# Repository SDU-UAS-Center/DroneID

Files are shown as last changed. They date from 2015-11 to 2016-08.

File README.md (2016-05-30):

# DroneID
This repository contains documentation of the DroneID project. DroneID is a research project launched by the University of Southern Denmark in collaboration with the Danish Transport and Construction Agency in 2015.

COPYRIGHT

The content of repository is copyrighted by the respective authors mentioned in documents etc. 

LICENSE

Documentation of DroneID prototype hardware is, unless other information is indicated within the documentation, released under an Attribution 4.0 International(CC BY 4.0) license http://creativecommons.org/licenses/by/4.0/

CONTACT INFORMATION

University of Southern Denmark
Kjeld Jensen
Cand.Scient., PhD
SDU UAS Center
Campusvej 55
DK-5230 Odense M
Denmark

kjen@mmmi.sdu.dk
Phone: +45 27781926

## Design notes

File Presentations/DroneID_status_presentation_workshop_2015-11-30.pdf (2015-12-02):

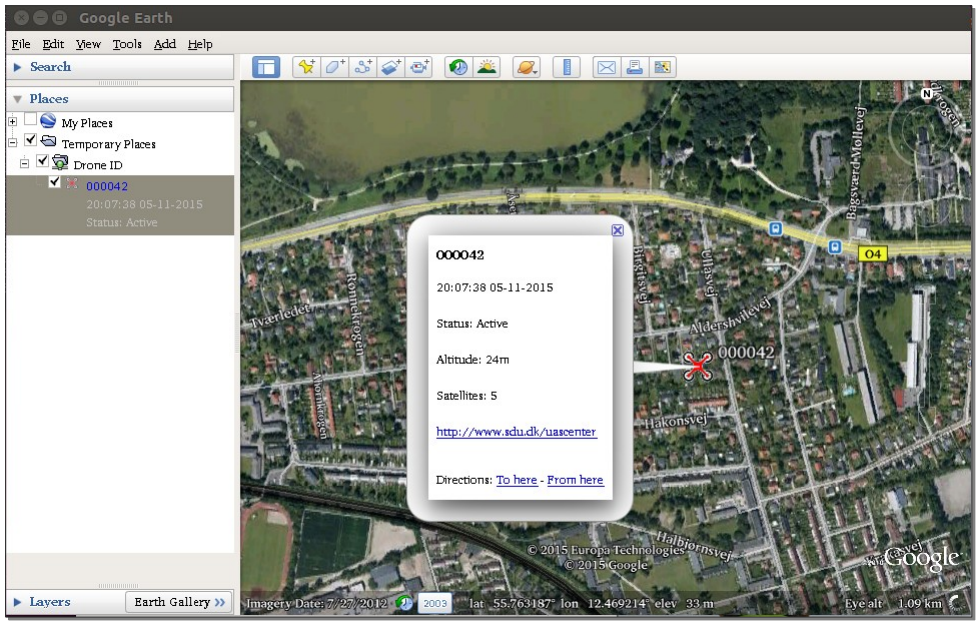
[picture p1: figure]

Workshop, Danish Transport and Construction Agency
Kjeld Jensen | November 30th, 2015
Cand.Scient. PhD
SDU UAS Center

## Drone ID

Drone identification and activity monitoring.

# Agenda

1.Welcome
2.Presentation of the project and tentative results.
3.Presentation of Apps for drone flight registration.
4.Presentation af a DroneID prototype based on on-site monitoring. 5.Feedback on the presentations.
6.Transport to the model airfield Celinevej, Amager.
7.Live demonstration of DroneID prototypes and access to drone flight information for authorities.
8.Feedback on demonstrations and conclusion at the model airfield.

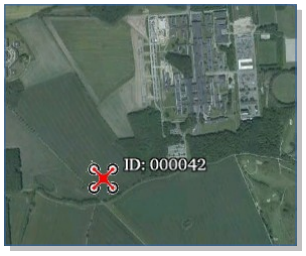
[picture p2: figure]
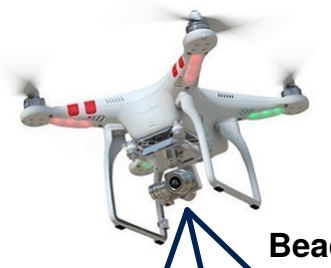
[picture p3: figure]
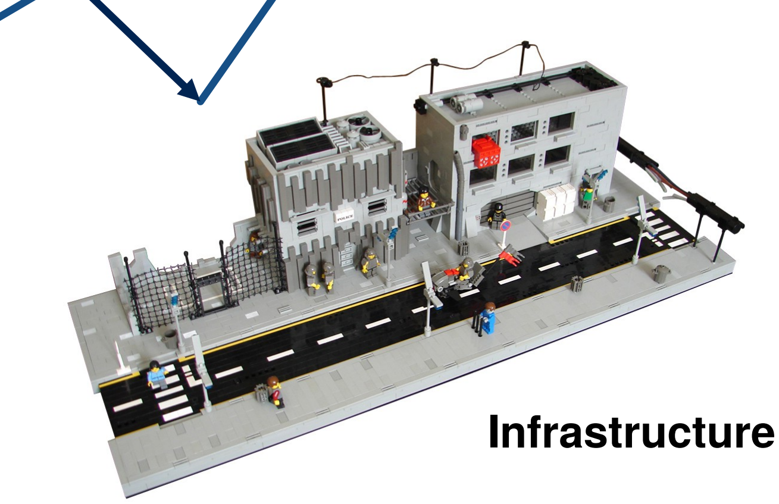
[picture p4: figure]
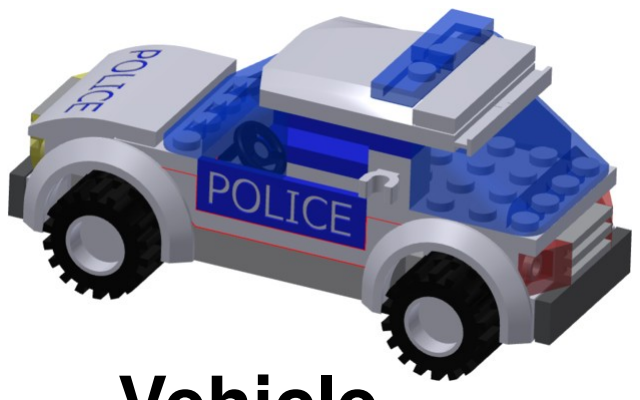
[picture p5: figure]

Handheld | Vehicle | Infrastructure

Access

# Drone ID architecture

On-site monitoring

Drone flight
pre-registration
Beacon | UAS Traffic Management (UTM)

Access

# Drone ID architecture

Network

Drone flight
pre-registration

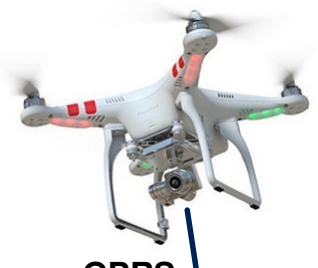
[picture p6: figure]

GPRS
modem

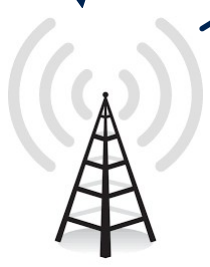
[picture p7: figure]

Cell tower

UAS Traffic
Management (UTM)

Flight
- Activity ID
- Status
- Start
- End
- Geofence
- Type
- Purpose

unique
planned/ongoing/completed/cancelled date and time
date and time
polygon describing boundary of operation commercial/recreational
specified e.g. training/inspection/transport etc. Drone
- Drone ID
- Type
- Payload
Pilot
- Name
- Address
- Phone
- Email
- Company
Authorization
- Status
- Authorities

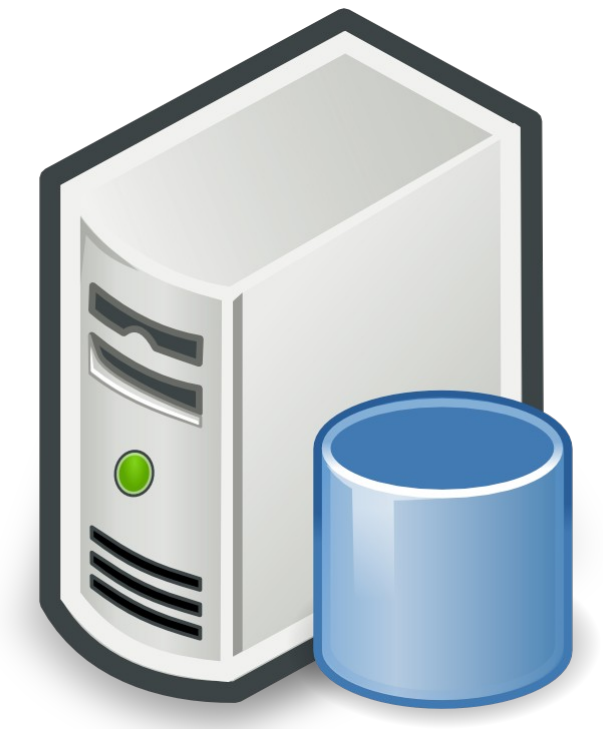
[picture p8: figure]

issued by authority
autofill if ID is available e.g. camera/sensor

not required/pending/approved/denied autofill based on location and drone ID

Activity records will automatically be validated (based on drone ID and geofencing) against static and dynamic restricted zones and submitted for approval by relevant authority.

# Drone ID record

UAS Traffic
Management (UTM)

Hardware
- Self contained, no interface to drone
- Very small form factor
- Light weight
- Low power operation
- Beacon interval 1 second
- Optional GPS and altimeter

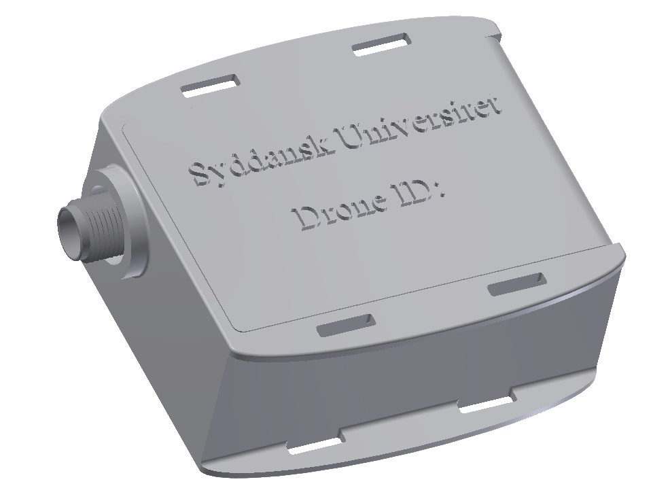
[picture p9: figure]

Beacon data
- Unique ID issued by authority
- Optional data (based on sensors):
- Position, elevation
- Velocity, heading
- Flight time
- Rolling key encryption to prevent unauthorized access and spoofing

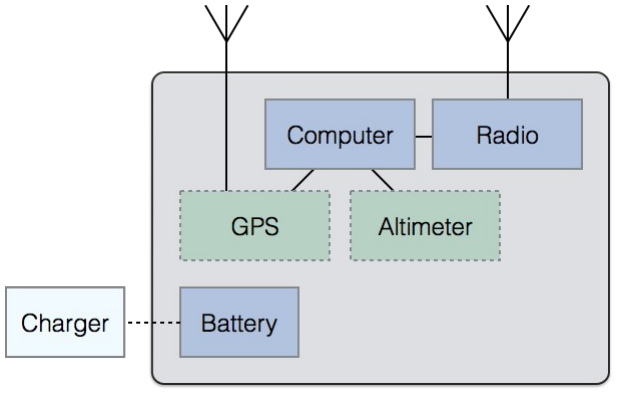
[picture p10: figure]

Hardware modules

# Drone ID prototype

# Drone ID beacon

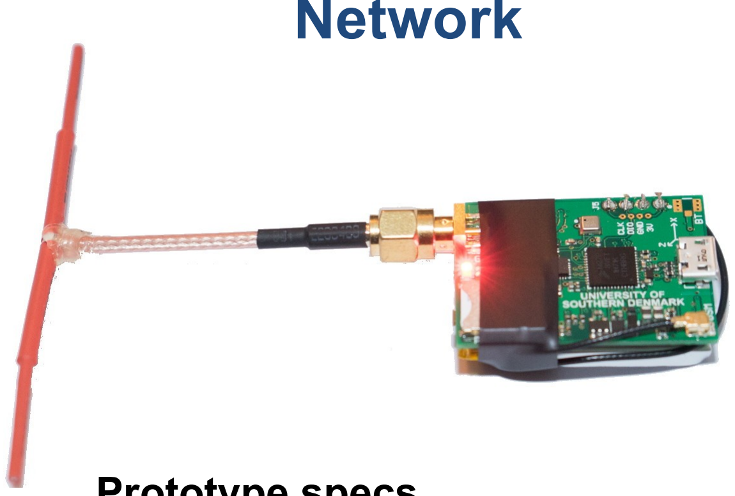
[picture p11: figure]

Prototype specs.
› GPRS modem
› GPS with external dipole antenna* › Weight approx. 20 g
› No connections to the drone
› Micro USB charging
› Battery lasts approx. 3 hours of flight time.

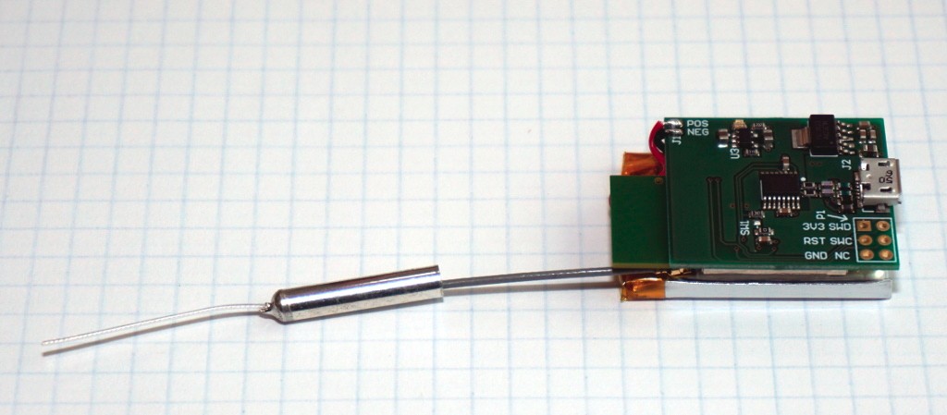
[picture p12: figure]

Prototype specs.
› Wifi radio
› External 2.4 GHz antenna › Weight approx. 10 g
› No connections to the drone › Micro USB charging
On site monitoring | Network
- Expected working range 500 - 1000m
- May require receiver hardware, antenna etc.
- No ground based infrastructure.
+ Lower size, weight, power.
+ Lower price
- Coverage limited by network (potential MVNO roaming). + No receiver hardware needed.
+ Infrastructure already established
- Higher size, weight, power.
- Higher price.
- Requires SIM card and subscription.

*The external dipole antenna allows installation of the DroneID on the side or beneath the drone body.

# Implementation road map

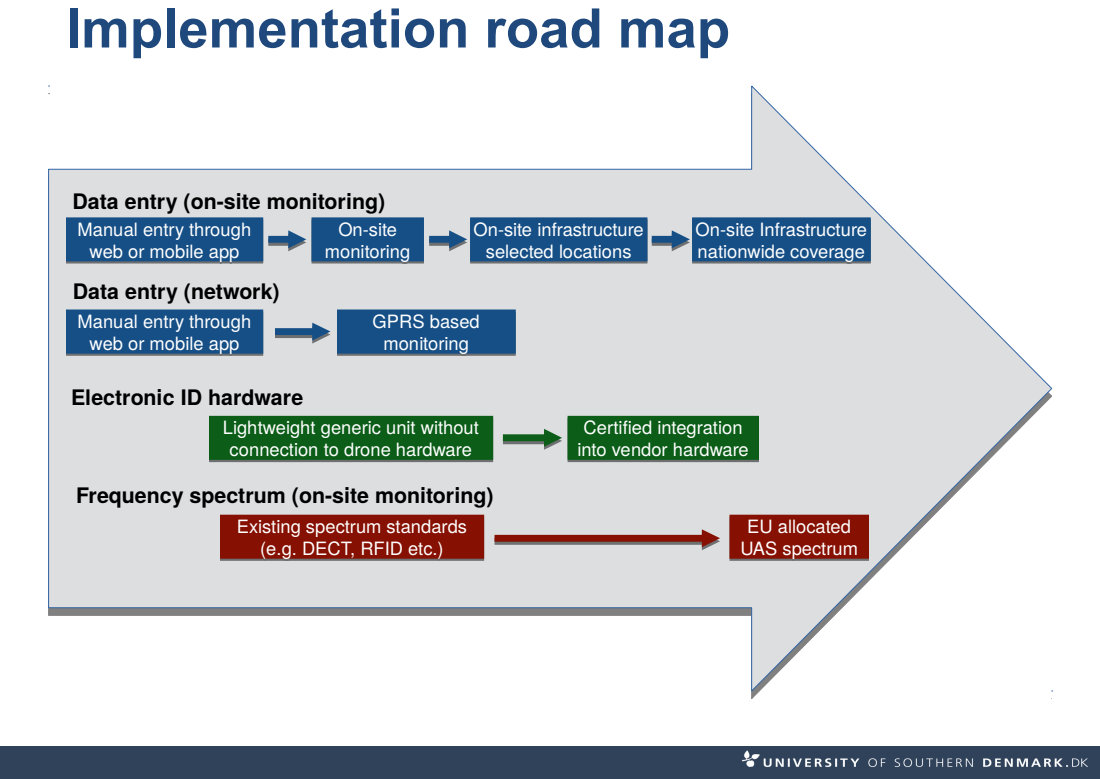
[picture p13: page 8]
On-site monitoring; EU allocated UAS spectrum; GPRS based monitoring

Data entry (on-site monitoring)
Manual entry through
web or mobile app
Data entry (network)
Electronic ID hardware

On-site infrastructure
selected locations

On-site Infrastructure
nationwide coverage

Lightweight generic unit without
connection to drone hardware

Certified integration
into vendor hardware

Frequency spectrum (on-site monitoring)

Existing spectrum standards
(e.g. DECT, RFID etc.)

# Current experiment

- 10 drone operators use a GPRS/GPS based DroneID prototype for one month starting mid November 2015.
- Workshops with drone operators, industrial partners, the police and other stakeholders focusing on user experience and feedback, on-site monitoring demonstrations, etc.
- Documentation completed ultimo 2015.
- Hardware and software developed by SDU within the project released as open source.

Companies contributing to the project
› DroneSoft ApS (mobile App showcase)
› Resiewe A/S (on-site DroneID prototype showcase)
› Scandinavian Avionics A/S (on-site DroneID prototype showcase)

Partners
› Danish Transport and Construction Agency › University of Southern Denmark
› UAS Denmark

# Startup workshops

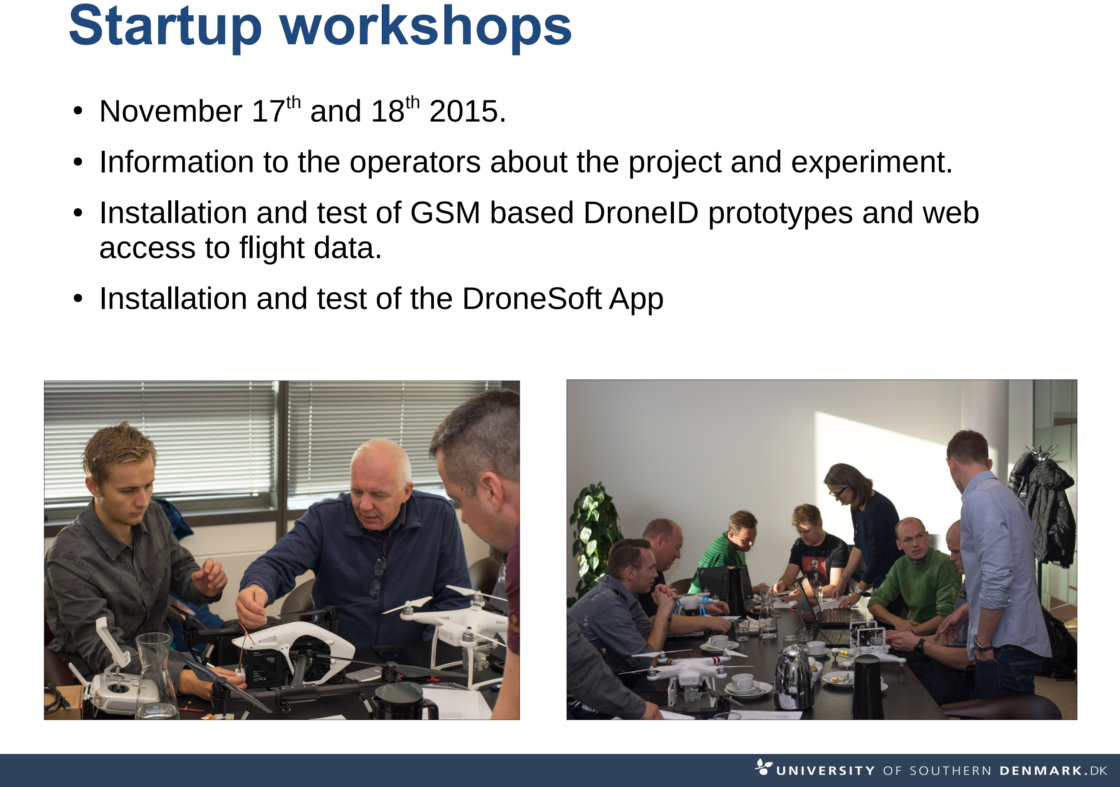
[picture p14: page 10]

- November 17th and 18th 2015.
- Information to the operators about the project and experiment.
- Installation and test of GSM based DroneID prototypes and web access to flight data.
- Installation and test of the DroneSoft App

# Installation guidelines

- DroneID must be installed on the side or beneath the drone body unless it can be ensured that the drone GPS antenna is not obstructed.
- DroneID must be installed as far away from other antennas with the DroneID logo (and hence GSM antenna) facing away from the drone body.
- DroneID GPS dipole antenna must have a clear view of the sky without obstructing the drone GPS antenna or touching the propellers. Antenna and cable should not be directly parallel to or near other antennas.
- Mount using electrical tape, velcro, cable binders etc.

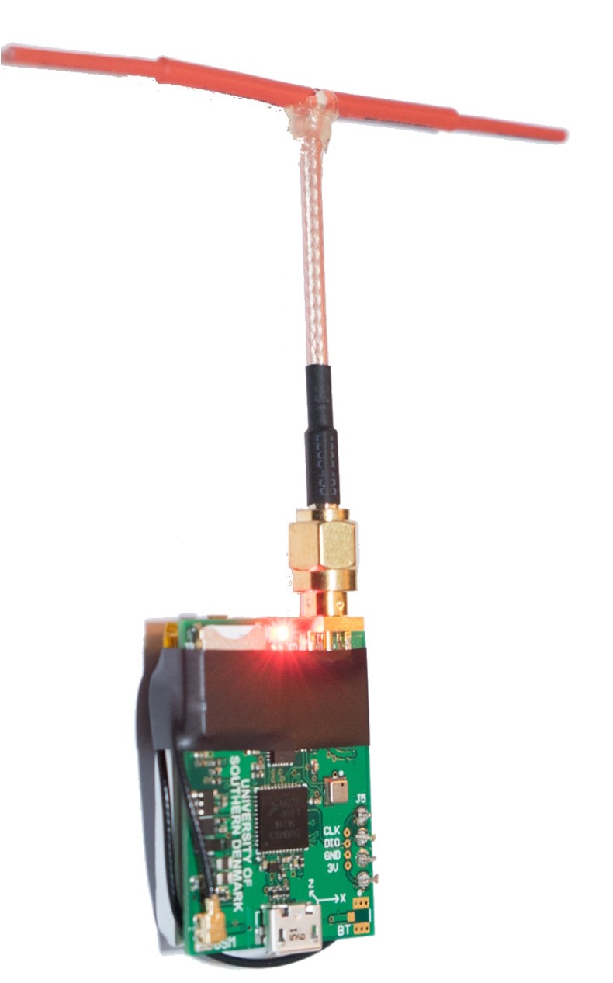
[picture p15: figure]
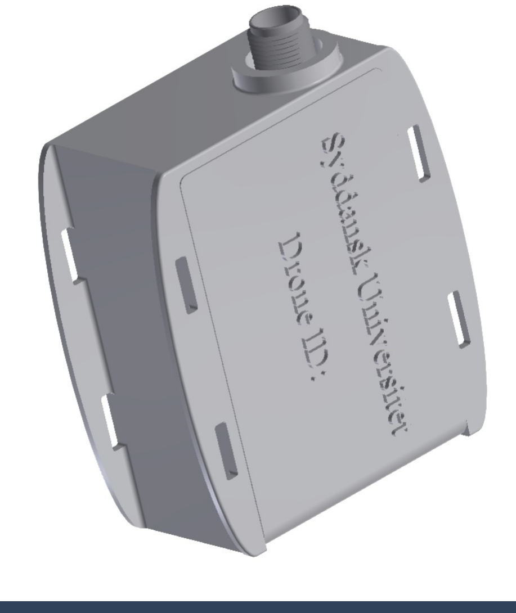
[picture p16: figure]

# Installation examples

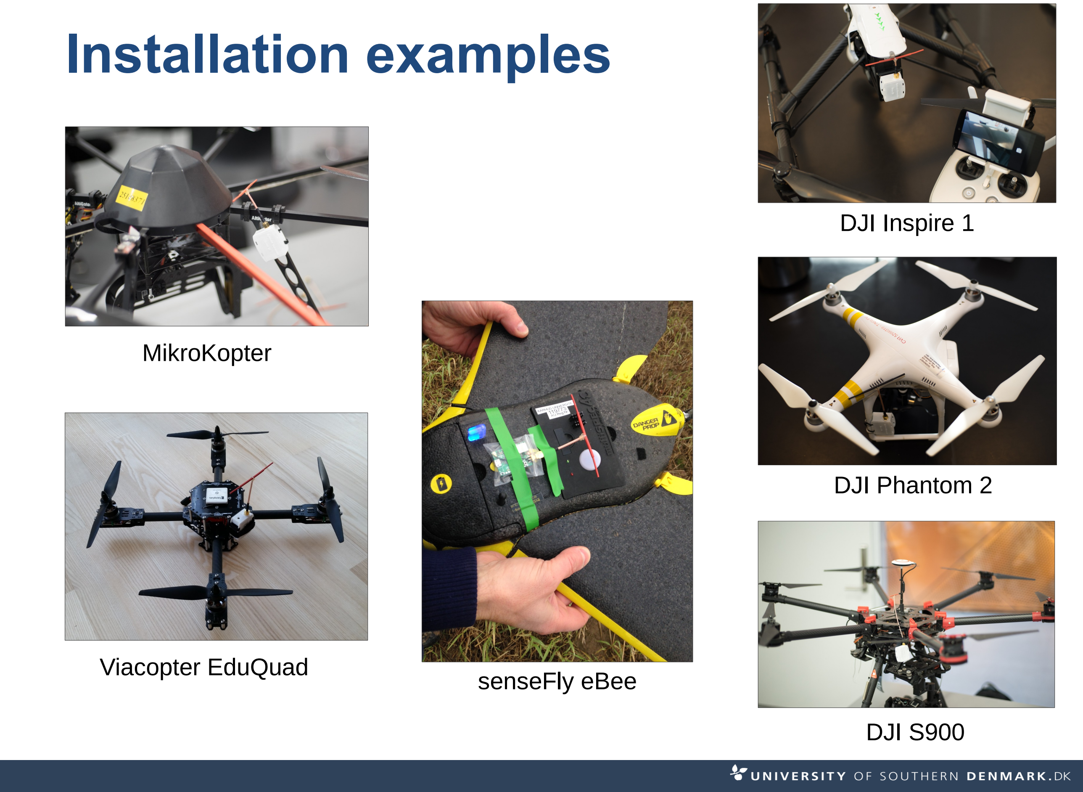
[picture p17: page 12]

DJI Inspire 1

DJI Phantom 2

senseFly eBee

DJI S900

MikroKopter

Viacopter EduQuad

# Crop surveying example

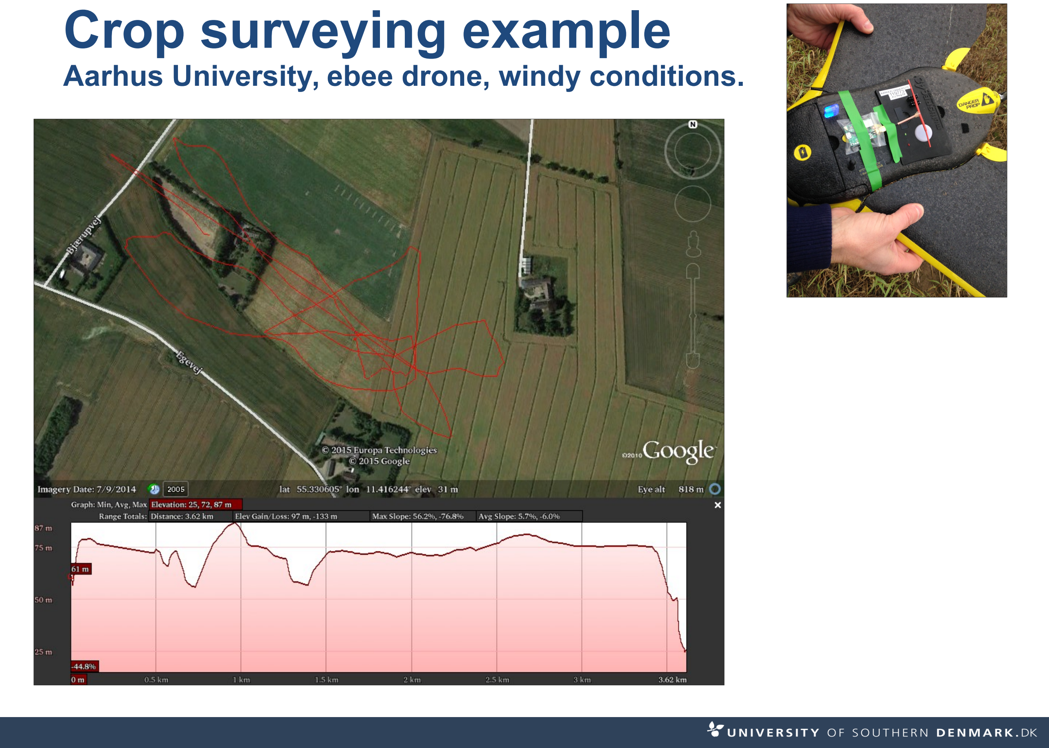
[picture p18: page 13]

Aarhus University, ebee drone, windy conditions.

# Manual inspection example

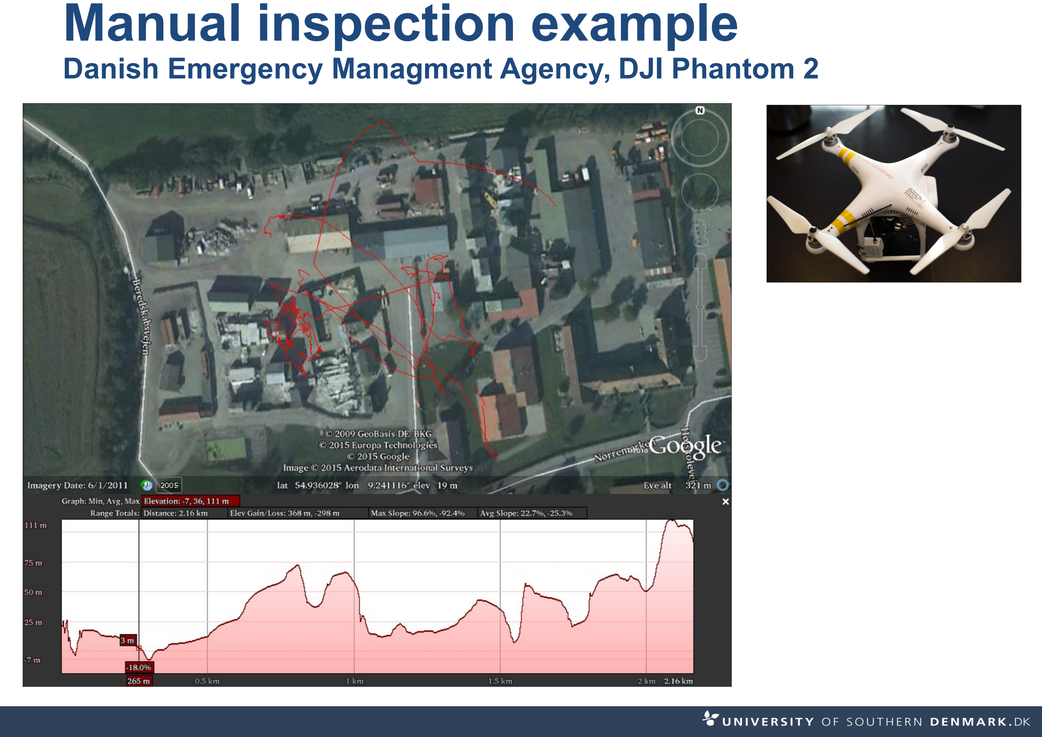
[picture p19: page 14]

Danish Emergency Managment Agency, DJI Phantom 2

# Test flight example

Odense Municipality, DJI Inspire 1

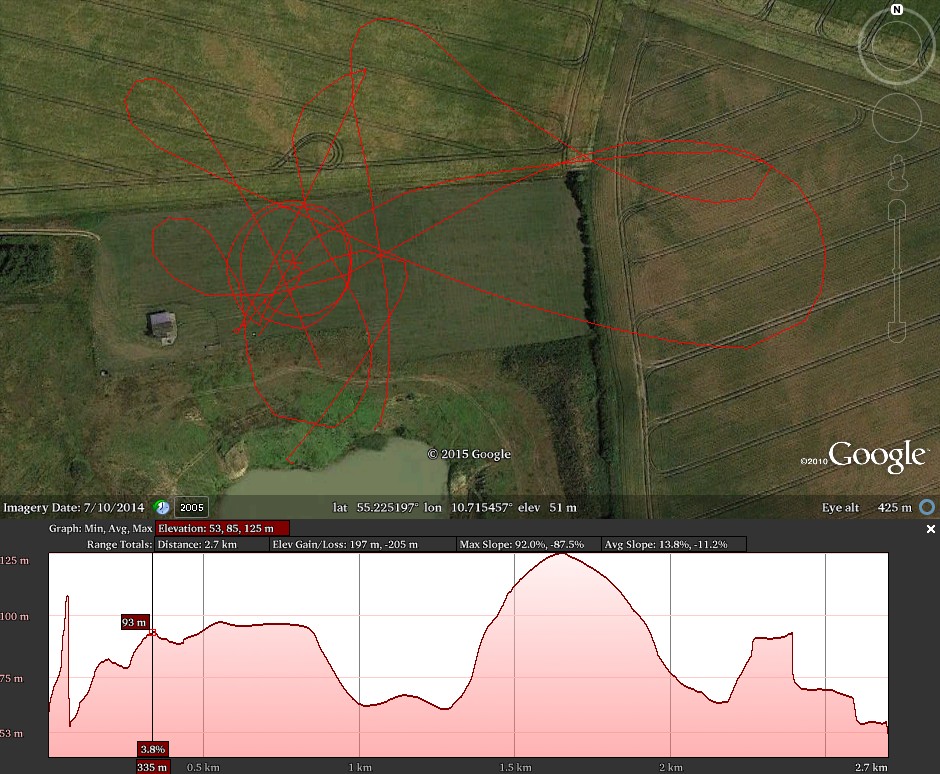
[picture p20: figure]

# GPS track comparison

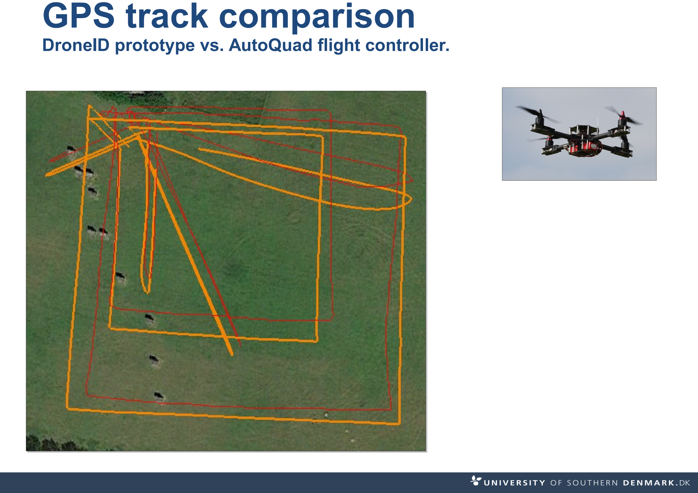
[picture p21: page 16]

DroneID prototype vs. AutoQuad flight controller.

# Some tentative conclusions

- The DroneID prototype seems to work to the extent tested. Errors and deficiencies discovered so far can be fixed in software or hardware.
- Data from the DroneID barometer and IMU will add valuable information when analyzing the drone state etc.
- User interface is too complicated. The operator already has many things on his mind while planning and performing flights. A simpler user interface will be tested on select operators for the rest of the experiment period.
- Despite a fairly high battery capacity the use pattern sometimes causes the battery to run flat. This may be solved in software. Remaining battery time must be clearly indicated, ideally through the app.

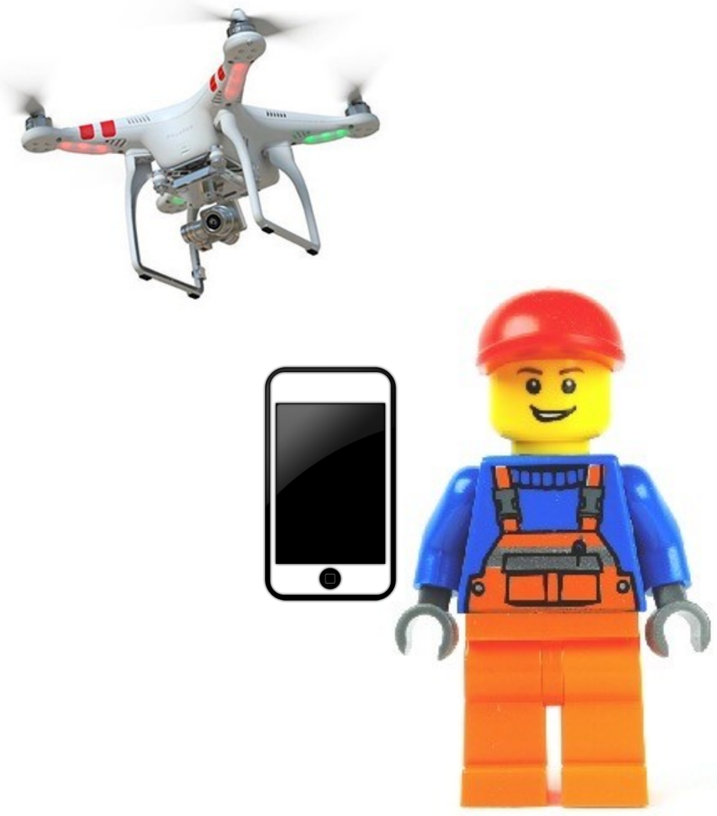
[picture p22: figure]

Kjeld Jensen
Cand.Scient. PhD
SDU UAS Center
Phone +45 27781926
Email: kjen@mmmi.sdu.dk

# Thank you for listening!

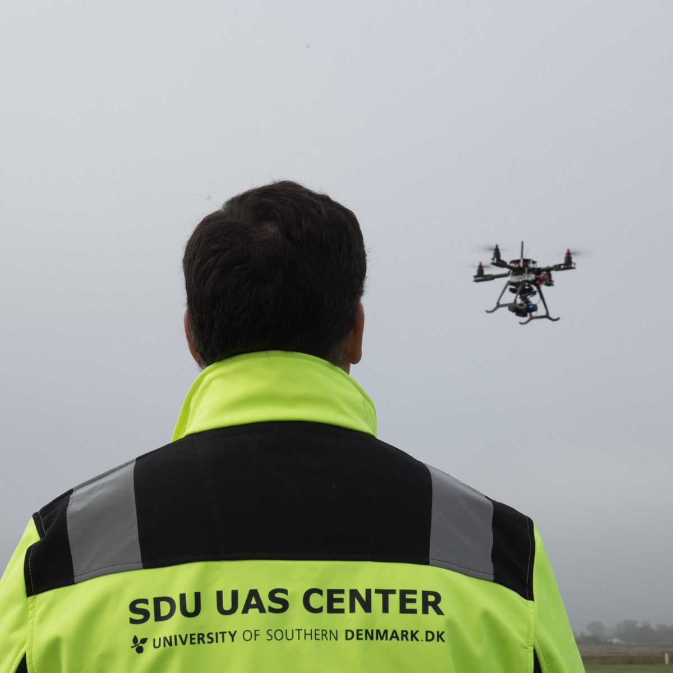
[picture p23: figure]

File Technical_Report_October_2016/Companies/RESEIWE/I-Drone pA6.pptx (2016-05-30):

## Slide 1

RESEIWE A/S, Niels Jernes Vej 10, 9220 Aalborg

Resilient Wireless Links for
Mission Critical applications
- On existing equipment and standards

Products
- Satellite links
- Resilient industrial links (Wi-Fi)
- UAV Control links (433MHz and Wi-Fi)

With RESEIWE technology

Still images
Full control

Control only

Operating range.
Full video

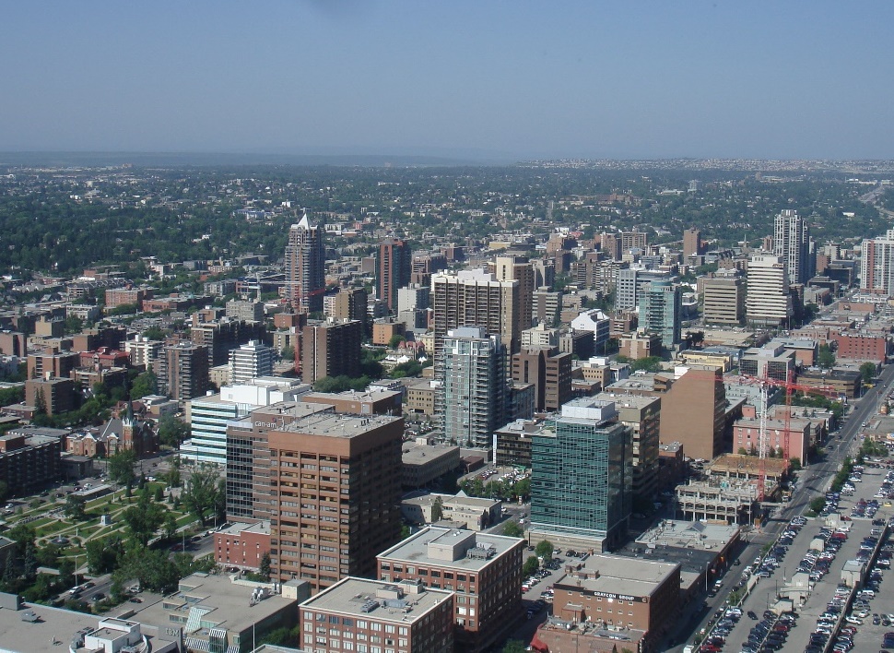
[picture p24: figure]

RESEIWE
Technology
added


UAV: Normal operation

Dead spots

Operating range.
Full video

Niels-Christian Gjerrild
ncg@reseiwe.com
+45 4034 9879

## ReWiLink (Wi-Fi)

RESEIWE DroneID SW on standard Wi-Fi module

Detect and avoid

ReWiLink (Wi-Fi)

RESEIWE App

ReWiLink (Wi-Fi)

ReWiLink (Wi-Fi)

RESEIWE App

Demonstration

ReWiLink (Wi-Fi)

RESEIWE Reader

GSM

Pilot
- Report to log via GSM (smartphone app)
- Storing log for later report if no GSM coverage
- Lookup in database

GSM network

Private
- Direct read (smartphone app)
- Lookup in database

Drone flight registration database

Police
- Direct read
- Point and identify (directional reader)
- Lookup in database

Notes: Wi-Fi: Readable of standard smartphone with App

Reporting App on Pilot phone: Relaying to database
And buffering if no mobile coverage – reporting when within coverage

## Demo


- Prototype til demo
- PC interface med tekst udlæsning af position
  - Kan integreres med kort
- Kan integreres i eksisterende udstyr
- Rækkevidde
  - Læser: 2.2 km
  - Smartphone: Afhængig af antenne i telefon


## EASA A-NPA 2015-10

© RESEIWE A/S


## ReWiLink (Wi-Fi)

RESEIWE DroneID SW on standard Wi-Fi module

Detect and avoid

ReWiLink (Wi-Fi)

RESEIWE App

ReWiLink (Wi-Fi)

ReWiLink (Wi-Fi)

RESEIWE App

ReWiLink (Wi-Fi)

RESEIWE Reader

GSM

Pilot
- Report to log via GSM (smartphone app)
- Storing log for later report if no GSM coverage
- Lookup in database

GSM network

Private
- Direct read (smartphone app)
- Lookup in database

Drone flight registration database

Police
- Direct read
- Point and identify (directional reader)
- Lookup in database

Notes: Wi-Fi: Readable of standard smartphone with App

Reporting App on Pilot phone: Relaying to database
And buffering if no mobile coverage – reporting when within coverage

## VDL Mode 4

Detect and avoid

VDL Mode 4

VDL Mode 4

VDL Mode 4

Pilot
- Lookup in database

GSM network

Private
- Lookup in database

Police
- Direct read
- Lookup in database

VDL Mode 4 network

Drone flight registration database

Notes: Wi-Fi: Readable of standard smartphone with App

Reporting App on Pilot phone: Relaying to database
And buffering if no mobile coverage – reporting when within coverage

## VDL Mode 4 & ReWiLink

VDL Mode 4 & ReWiLink (Wi-Fi)

Detect and avoid

RESEIWE App

ReWiLink (Wi-Fi)

ReWiLink (Wi-Fi)

RESEIWE App

VDL Mode 4 & ReWiLink (Wi-Fi)

VDL Mode 4

GSM

Pilot
- Report to log via GSM (smartphone app)
- Storing log for later report if no GSM coverage
- Lookup in database

GSM network

Private
- Direct read (smartphone app)
- Lookup in database

Drone flight registration database

Police
- Direct read
- Point and identify (directional reader)

VDL Mode 4 network

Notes: Wi-Fi: Readable of standard smartphone with App

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

## GSM

GSM

GSM

Pilot
- Lookup in database

GSM network

Private
- Lookup in database

Police
- Lookup in database

Drone flight registration database

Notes: Wi-Fi: Readable of standard smartphone with App

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

## Test flight Dec. 14, 2015


- Test flight at HCA Airport, Odense
- ReWiLink Drone ID trace
- Log via SDU database

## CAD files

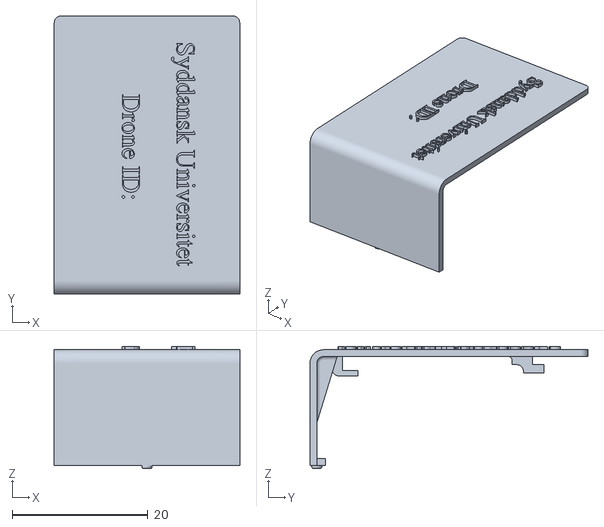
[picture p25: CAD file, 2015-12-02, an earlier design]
DroneID_V1_device/Cabinet_3D_print/00-00-002.stl
27.3 x 40.9 x 18.0

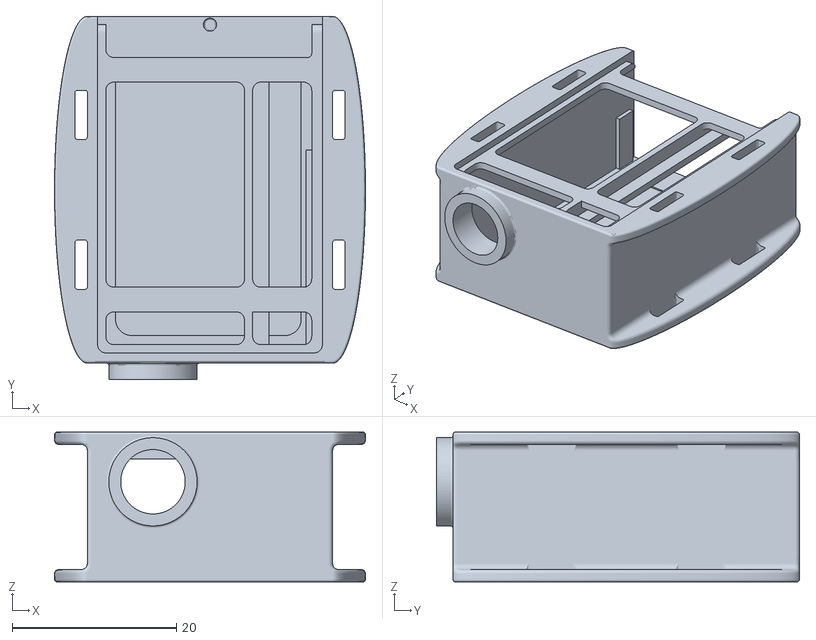
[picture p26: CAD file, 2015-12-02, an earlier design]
DroneID_V1_device/Cabinet_3D_print/00-00-001.stl
37.9 x 44.2 x 18.2

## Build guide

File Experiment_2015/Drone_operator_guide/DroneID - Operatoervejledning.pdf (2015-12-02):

# DroneID Operatørvejledning

Version 2015-11-20, Kjeld Jensen kjen@mmmi.sdu.dk

# Indholdsfortegnelse

Indholdsfortegnelse
Forkortelser
Indledning
Hvorfor deltage
Hvad skal du gøre
Ansvar
Regler for brug af data
Forsøgets forløb
DroneID prototype
Installationsvejledning
Brugervejledning
Tilstande
Skift mellem tilstande
Lysdioder
Logbogen
Checklister
Checkliste ved dagens planlægning af flyvning Checkliste før flyvning
Checkliste under flyvning
Checkliste efter flyvning
Checkliste ved afslutning af dagens flyvning Adgang til logfiler
TXT log beskrivelse
Projekt dokumentation

# Forkortelser

AIC B 08/14 (https://www.trafikstyrelsen.dk/~/media/Dokumenter/05%20Luftfart/Forum/UAS%20-%20droner/AIC%20B%2008%202014.ashx) Erhvervsmæssig mv. brug af ubemandede fartøjer (UAS/RPAS) i Danmark
BL9-4 (http://selvbetjening.trafikstyrelsen.dk/civilluftfart/Dokumenter/Love%20og%20bestemmelser/Bestemmelser%20for%20Civil%20Luftfart%20%28BL%29/BL%2009-serien/9_4_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) | Bestemmelser om luftfart med ubemandede luftfartøjer, som ikke vejer over
25
| kg.
GPS | Global Positioning System
GSM | Global System for Mobile Communications
KML (https://da.wikipedia.org/wiki/Keyhole_Markup_Language) | Filformat til visning af data på et kort (virker med eks. Google Earth)
NDA | Nondisclosure Agreement
SDU (http://www.sdu.dk/) | Syddansk Universitet (SDU UAS Center)
TBST (http://www.tbst.dk/) | Trafik og Byggestyrelsen

# Indledning

Trafik og Byggestyrelsen (http://www.tbst.dk/) (TBST) og SDU UAS Center (http://www.sdu.dk/uascenter) ved Syddansk Universitet (SDU) har i efteråret 2015 indgået en aftale om et længerevarende forskningssamarbejde for at understøtte og fremme udviklingen af teknologiske og infrastrukturmæssige løsninger, der muliggør en effektiv og sikker anvendelse af flyvende droner med sigte på en positiv erhvervsmæssig udvikling i Danmark.

DroneID, der er det første projekt under samarbejdsaftalen, handler om at undersøge muligheden for at udrulle et system til identifikation og monitering af aktivitet for droner til brug for luftfarten, politiet og andre relevante myndigheder. Projektet bygger ovenpå et arbejde udført af regelgruppen under UAS Denmark. (http://www.uasdenmark.dk/) Projektet er også blevet omtalt som dronenummerplader, elektronisk ID, I-drone mv.

SDU ønsker at afprøve brugen af DroneID i praksis og har derfor etableret et forsøg. I forsøget udleveres DroneID prototyper til 10 aktive droneoperatører i Danmark, som så flyver rundt med disse påmonteret deres drone i ca. en måned. Målet er at få opsamlet måledata samt praktisk erfaring til brug for TBST’s videre arbejde med DroneID.

Dokumentet her er en operatørvejledning indeholdende relevant information til de operatører, der deltager i forsøget. For en uddybning af projektet og øvrige aktiviteter henvises til forsøgets startmøder, hvor det vil blive gennemgået.

# Hvorfor deltage

Den vigtigste grund til at deltage i forsøget er, at droneindustrien i Danmark har brug for de bedst mulige arbejdsforhold under hensyntagen til den nødvendige sikkerhed. DroneID er en af de komponenter, som kan bidrage til dette, idet det giver eks. luftfartsmyndigheder og politi et vigtigt og efterspurgt arbejdsredskab.

Derudover har du som operatør også nogle mere direkte fordele ved at deltage i projektet:

- Du bliver blandt de første operatører, som får detaljeret viden om DroneID fra os og via dine egne erfaringer i forsøgsperioden.
- Vi er meget interesserede i en løbende dialog med dig under forsøget, så du får god mulighed for at komme med ideer, forslag, spørgsmål, kommentarer mv.
- Vi giver dig online adgang til dine egne data, både som en processeret KML fil, der kan vise din flyvning i eks. Google Earth på dagsbasis samt som rå data, hvis du selv ønsker at processere dem.

# Hvad skal du gøre

- Flyve med DroneID prototypen så ofte som muligt og gerne på flere forskellige dronetyper, så vi får flest mulig data registreret.
- Efter hver flyvning udfylde logbogen så vi dels får referencedata for dine flyvninger og dels modtager dine erfaringer med brugen af DroneID.
- Sende os en kort beskrivelse og billeder af installationen af DroneID på din(e) drone(r), så vi får opsamlet erfaring med de udfordringer, der kan være omkring installationen.
- Kontakte os, hvis du oplever problemer, vi ønsker en løbende dialog med alle operatører.

# Ansvar

Deltagelse i forsøget er frivilligt for operatøren. Operatørens deltagelse i forsøget er betinget af, at operatøren opfylder minimum et af de to følgende krav:
1) Operatøren er forsikret i overensstemmelse med reglerne beskrevet i AIC B 08/14 samt i forordning EC 755/2004.
2) Operatøren flyver under BL9-4 og har tegnet en ansvarsforsikring, som dækker droneflyvningen, eks. gennem medlemsskab af Modelflyving Danmark.

DroneID prototyperne er SDU’s ejendom og skal returneres til SDU efter forsøgets afslutning, med mindre andet aftales med SDU. Operatører, der deltager i forsøget, vil ikke blive holdt ansvarlig for evt. skader på en udleveret DroneID prototype, ud over skader der er påført ved grov uagtsomhed eller med forsæt.

Hvis DroneID prototypen bortkommer eller på anden vis bliver gjort tilgængelig for tredjepart, skal operatøren øjeblikkeligt kontakte Kjeld Jensen på kjen@mmmi.sdu.dk eller telefon 27781926. Årsagen er, at DroneID prototypen indeholder et SIM kort, som kan misbruges, og derfor skal spærres.

Besked fra TBST vedr. forsøget: “Trafik og Byggestyrelsen er indforstået med installation af DroneID prototypen på dronerne, og operatørerne må flyve med dem under operatørernes gældende dispensation. Operatørerne skal dog udføre første flyvning med DroneID prototypen monteret efter BL9-4 og denne flyvning skal have en varighed på min 10 minutter. På den måde får vi en verifikation af at DroneID prototypen ikke forstyrrer dronen på en BL9-4 lokation, hvor risikoen vil være mindre end inde i et byområde.”

# Regler for brug af data

Som operatør bestemmer alene du, hvornår du ønsker at flyve med DroneID prototypen installeret. Fra SDU’s side ønsker vi så mange måledata som muligt, men vi har selvfølgelig forståelse for, at der kan være flyvninger, som du måtte ønske at hemmeligholde for forsøget. Herunder er en nærmere beskrivelse af, hvordan vi bruger data.

DroneID prototyperne har mulighed for at sende følgende data til en server administreret af SDU: tid, status, position, højde, kvalitet af GPS signal, batteriniveau. Disse data vil blive benyttet af SDU til kvalitative og kvantitative evalueringer af forsøget. Resultatet af disse evalueringer vil blive offentliggjort i publikationer udarbejdet af SDU men kun i en anonymiseret form, som ikke kan spores tilbage til den enkelte droneoperatør.

SDU samarbejder med virksomheden DroneSoft ApS, der i forsøgsperioden løbende modtager data fra DroneID prototyperne (videresendt fra SDU). DroneSoft ApS benytter data i forbindelse med deres udvikling af en database og tilhørende App til brug for droneoperatører. SDU har indgået en Nondisclosure Agreement (NDA) som forpligter DroneSoft ApS til at behandle de modtagne data fortroligt. I det omfang at DroneSoft ApS benytter underleverandører og samarbejdspartnere i deres projekt, er de omfattet af samme forpligtigelse.

I forbindelse med forsøget afholdes to workshops for myndigheder og slutbrugere. På disse workshops vil deltagerne få lejlighed til at betjene DroneSoft apps, som giver adgang til registrerede flyvninger mv. Du må derfor forvente, at der kan blive kigget på dine flyvninger, men fokus er på funktionalitet og betjening af app’s og ikke på de registrerede data.

SDU ønsker at understøtte DroneSoft ApS i deres arbejde, og ser derfor en fordel i, at også de modtager så meget data som muligt. Men hvis du som operatør ikke ønsker, at dine data videresendes til DroneSoft ApS og dermed kan blive anvendt under de beskrevne forhold, kan du kontakte Kjeld Jensen, som vil sikre at dette ikke sker fremadrettet.

# Forsøgets forløb

Inden opstart
Operatører udvælges.
Operatører får tilsendt en tidlig version af operatørvejledningen
Operatører registrerer information på http://uaslab.dk/droneid/operatoerreg (http://uaslab.dk/droneid/operatoer-reg)

Startmøder 17 & 18. november
For operatører nær København:
Tirsdag 17. november 2015 klokken 9.30 12.00
Trafik og Byggestyrelsen
Edvard Thomsens Vej 14
2300 København S
Møderum F
For operatører nær Odense:
Onsdag 18. november 2015 klokken 8.00 10.00 Syddansk Universitet

Campusvej 55
5230 Odense M
Nærmere detaljer omkring mødelokale mv. fremsendes til deltagere. Dagsorden:
1. Velkomst (TBST)
2. Velkomst og introduktion til DroneID (SDU)
3. Gennemgang af forsøget (SDU)
4. Gennemgang af DroneSoft App (DroneSoft)
5. Workshop installation af prototyper og App oprettelse
6. Evt.

Afslutning
Operatører returnerer DroneID prototype 30 dage efter udlevering. Opfølgende fælles møde hvis ønsket.

# DroneID prototype

DroneID prototypen består af en lille kasse. Ud fra kassen er der et antennestik til en GPS-antenne samt et micro-USB stik til opladning af prototypens batteri. På billedet kan du se prototypen med GPS-antenne monteret men uden kabinet.

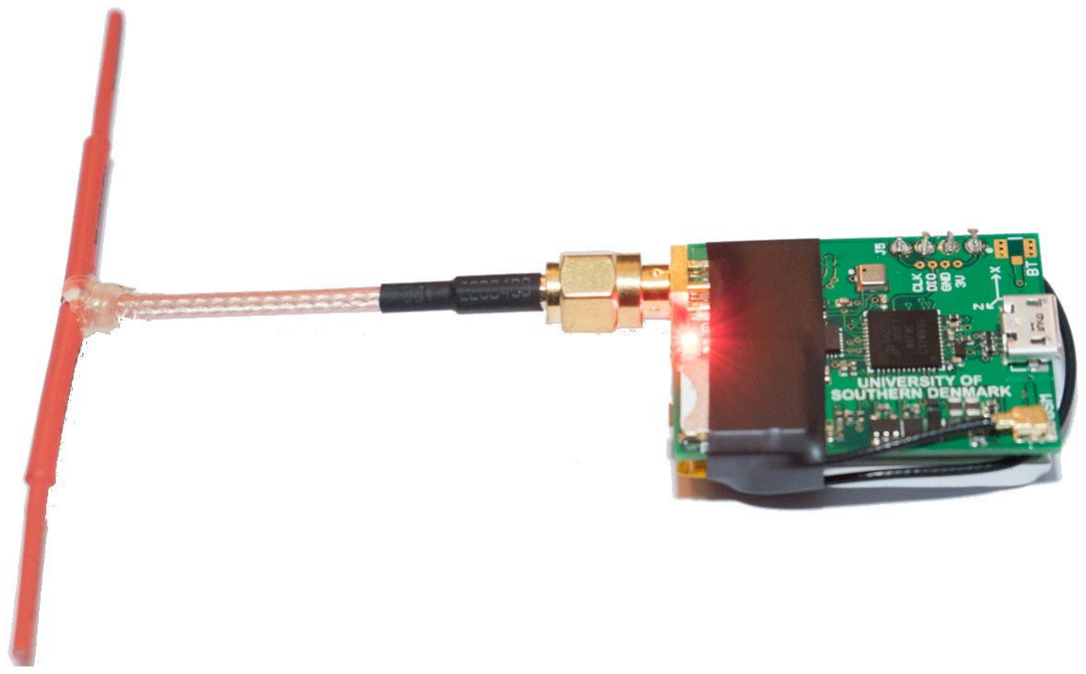
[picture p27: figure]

DroneID prototypen vejer ca. 20g med GPS-antenne men uden kabinet.

GPS-antennen leveres med varierende kabellængde alt efter den mest hensigtsmæssige installation på din drone.

DroneID prototypens kabinet kan ses på billedet herunder. Vi er ikke nået så langt med udviklingen af dette, men uanset er det interessant at få det testet ude på dronerne for at få noget erfaring med, hvad der virker og ikke virker. Kabinettet ikke vandtæt og prototypen må derfor ikke udsættes for regn.

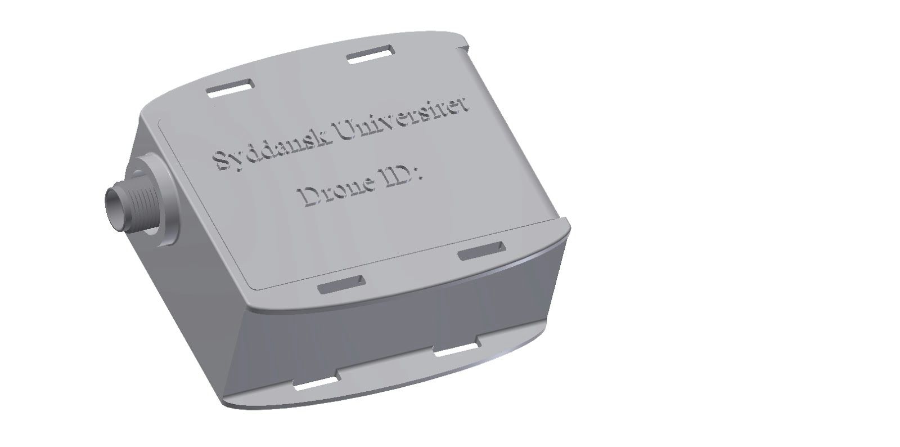
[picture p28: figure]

Blot til orientering: Kostprisen for DroneID prototypen er ca. 650 kr. plus moms for hardwaren (foruden 3d printet kabinet) og dertil kommer ca. 3 arbejdstimer til lodning af komponenter og montage. Det afspejler selvfølgelig ikke den pris som en evt. serieproduceret DroneID vil have.

# Installationsvejledning

DroneID prototypen kræver ingen elektriske forbindelser til dronen. Herunder er anbefalinger vedr. installationen:

- Prototypen kan monteres med tape, velcro, kabelbindere eller hvad der nu er mest praktisk. Hvis du anvender kabelbindere eller kraftig tape, så vær opmærksom på at kabinettet er en smule skrøbeligt på grund af den tynde materialetykkelse for at holde vægten nede.
- Forsiden af kassen indeholder en GSM-antenne, denne bør vende væk fra dronen, dels for at undgå forstyrrelser ift. andre radiosendere og modtagere på dronen og dels for at skabe bedst mulige forhold for antennen.
- GPS antennen skal placeres vandret således, at antennekablet vender nedad, og den vandrette del er ca. på højde med dronens egen GPS-antenne. Af hensyn til denne bør prototypens GPS-antenne ikke være placeret højere. Da GPS-antennen kun anvendes til modtagelse, kan den ikke forstyrre andre radiosendere og modtagere på dronen. Dog vil den som andet metal kunne reflektere en del af signalet fra andre antenner placeret parallelt med og tæt på enten GPS-antennen eller antennekablet, derfor bør andre antenner være placeret vinklet på og i en vis afstand fra GPS-antennen.

Hvis du har spørgsmål til installationen så kontakt Kjeld Jensen.

# Brugervejledning

DroneID betjenes ved hjælp af to knapper og en grøn og en rød lysdiode. De to knapper er til henholdsvis til start/reset og til at skifte tilstand. RESETknappen er monteret på kanten af printet omkring simkortet og TILSTANDknappen til at skifte tilstand er monteret på printets forside. Dioderne er placeret ved siden af GPS antennen på frontsiden.

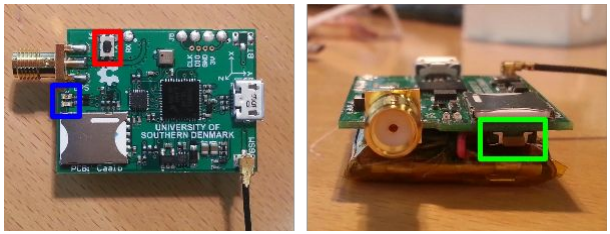
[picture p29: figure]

## Tilstande

Slukket
Bruges når DroneID opbevares i flere dage uden aktivitet Ingen aktivitet
Minimalt strømforbrug
Kræver tryk på RESETknap for at skifte til Stop
Stop
Bruges mellem flyvninger
DroneID computer tændt
Lavt strømforbrug
Klar
Bruges umiddelbart før flyvning DroneID computer og GPS tændt Data sendes ikke til server Mellem strømforbrug
Aktiv
Bruges under flyvning
DroneID computer, GPS og GSM tændt Data sendes til server
Højt strømforbrug

## Skift mellem tilstande

- DroneID er i stoptilstand efter tryk på RESET. Det indikeres ved 1 rødt blink.
- DroneID går til klartilstand, efter to hurtige klik på TILSTAND. Det kan tage op til et minut og indikeres med først 2 røde blink og derefter 3 røde blink. Hvis DroneID efter en periode med 2 røde blink går tilbage til 1 rødt blink, er det fordi DroneID ikke kan oprette forbindelse til serveren, typisk fordi DroneID er udenfor Telenor’s dækningsområde.
- DroneID skifter fra klartil aktiv tilstand efter to hurtige tryk på TILSTAND.

- Ved at trykke en enkelt gang på TILSTANDskifter DroneID til den forrige tilstand.
- DroneID kan altid slukketved at holde TILSTANDinde i ca. 2 sek indtil lysdioderne slukker.

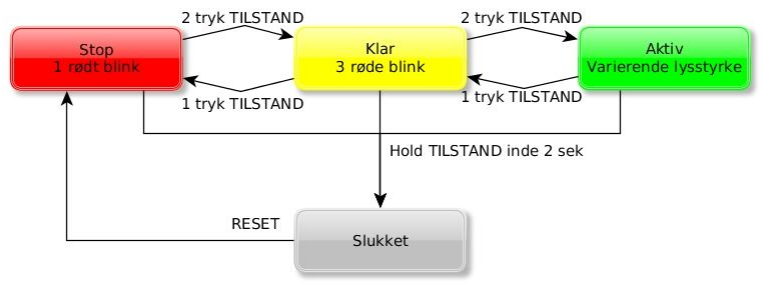
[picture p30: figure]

## Lysdioder

Rød lysdiode (Tilstand)
- Ingen lys: “Slukket”
- 1 blink: Nuværende tilstand Stop
- 2 blink: Næste tilstand Klar
- 3 blink: Nuværende tilstand Klar
- 4 blink: Næste tilstand Aktiv
- Svingende lysstyrke langsom: Nuværende tilstand Aktiv, ingen GPS fix
- Svingende lysstyrke hurtig: Nuværende tilstand Aktiv,GPS fix

Grøn lysdiode (GSM)
- Ingen lys: GSM slukket
- Blink mellem: GSM tændt
- Blink langsom: Etableret netværksforbindelse
- Blink hurtig: Forbindelse oprettet

# Logbogen

Logbogen finder du på adressen: http://uaslab.dk/droneid/logbog

Efter hver dag, hvor du har fløjet bedes du udfylde logbogen. Hvis der er forskel på dagens flyvninger, eks. forskellige steder, forskellige droner eller lignende, må du meget gerne udfylde logbogen flere gange.

Korte tests, hvor du aktiverer DroneID prototypen og slukker igen relativt hurtigt er der ingen grund til at registrere i logbogen, men laver du tests, hvor du eks. har den tændt svarende til en flyvning eller længere, kører en tur med den tændt eller lignende, så register det gerne i logbogen og beskriv kort, hvad du gjorde.

Laver du flyvninger med flere batteriskift i umiddelbar forlængelse af hinanden, behøver du ikke at deaktivere og aktivere DroneID hver gang. Men skriv gerne i logbogen, hvor mange landinger/batteriskift, du har foretaget.

# Checklister

## Checkliste ved dagens planlægning af flyvning

1. Husk at oplade DroneID prototypen
2. Tryk på DroneID RESETknappen for at sætte denne i Stoptilstand. Kontrollér at den røde lysdiode giver 1 blink.
3. DroneID monteres i huset og GPS antenne skrues på.

## Checkliste før flyvning

1. Tryk hurtigt to gange på TILSTANDknappen for at skifte til Klartilstand. Kontrollér at den røde lysdiode giver 2 blink og efter ca. 60 sekunder skifter til 3 blink.
2. Tryk igen hurtigt to gange på TILSTANDknappen for at skifte til Aktivtilstand. Kontrollér at den røde lysdiode giver 4 blink og derefter til svingende lysstyrke.
3. Kontroller at den svingende lysstyrke skifter hurtigt, hvilket viser at GPS har fix.

## Checkliste under flyvning

1. Notér dig evt. specielle forhold som kan være relevant ved en efterfølgende behandling af data fra DroneID prototypen.

## Checkliste efter flyvning

1. Kontrollér, at den rød lysdiode stadig har en hurtigt svingende lysstyrke, der indikerer, at DroneID er Aktiv og har GPS fix.
2. Deaktiver DroneID prototypen.
a. Tryk en enkelt gang på TILSTANDknappen, så DroneID går Klartilstand.
b. Hvis der er mere end en times tid til næste flyvning, tryk igen en enkelt gang på TILSTANDknappen, så DroneID går Stoptilstand.

## Checkliste ved afslutning af dagens flyvning

1. Sluk DroneID ved at holde TILSTANDknappen inde ca. 2 sekunder, til lysdioderne slukker.
2. Kig på logfil og kml fil for at identificere evt. problemer.
3. Udfyld logbogen http://uaslab.dk/droneid/logbog
4. Kan du uden besvær udtrække et GPS track over din flyvning, så send det gerne til kjen@mmmi.sdu.dk

# Adgang til logfiler

Som operatør har du adgang til din egen log. Du får ved forsøgets start udleveret et ID og en 4-cifret kode, som du skal bruge sammen med dit DroneID nummer for at se loggen.

Hvis du udskifter ‘000099’ og ‘adkl’ i adressen nedenfor med det udleverede, får du en log oversigt for de datoer, hvor du har fløjet.

http://uaslab.dk/droneid?id=000099?kode=adkl

For hver dato er der en TXT fil der indeholder de rå logdata samt en KML fil som du kan åbne i Google Earth. (http://earth.google.com/)

## TXT log beskrivelse

Loggen er separeret med TAB (ASCII karakter 9) og har følgende faste felter:
SEKUNDER TID | IP | TYPE

SEKUNDER er alm. tid siden 1. januar 1970
TID er tid på dagen (uden dato)
IP er DroneID prototypens IP adresse
TYPE er pakketypen, som kan være ACT, UPD, POS, OFF

Alt efter typen er de efterfølgende felter forskellige.

ACT
Sendes når operatøren aktiverer DroneID prototypen.

OFF
Sendes når operatøren deaktiverer DroneID prototypen.

UPD
Sendes med 1 sekunds interval, når GPS’en ikke har en opdateret position.

POS
Sendes med 1 sekunds interval, når GPS’en har en opdateret position. Efter TYPE feltet følger:

TID (UTC)
BREDDE
LÆNGDE
HØJDE
ANTAL SATELLITER

HDOP
BATTERISPÆNDING

Eksempel:

1447714830.042 | 00:00:30 94.144.63.26 | POS | 230027.000 | 55.384265 10.377948 15.1 | 44.0 | 6
1.4 3.20

# Projekt dokumentation

Projektaftalen mellem TBST og SDU fastlægger, at elektronisk og mekanisk design og udvikling af Drone ID prototyperne skal frigives under en permissive free open source licens, en licenstype, der understøtter kommercialisering på baggrund af den viden, som genereres i projektet. I praksis sker det for dokumenter og hardware under en Attribution 4.0 International (CC BY 4.0) (http://creativecommons.org/licenses/by/4.0/) licens, mens det for softwaren sker under en BSD 3-Clause (https://opensource.org/licenses/BSD-3-Clause) licens.

Relevant dokumentation fra DroneID projektet kan hentes på adressen: https://github.com/SDU-UAS-Center/DroneID (https://github.com/SDU-UAS-Center/DroneID)

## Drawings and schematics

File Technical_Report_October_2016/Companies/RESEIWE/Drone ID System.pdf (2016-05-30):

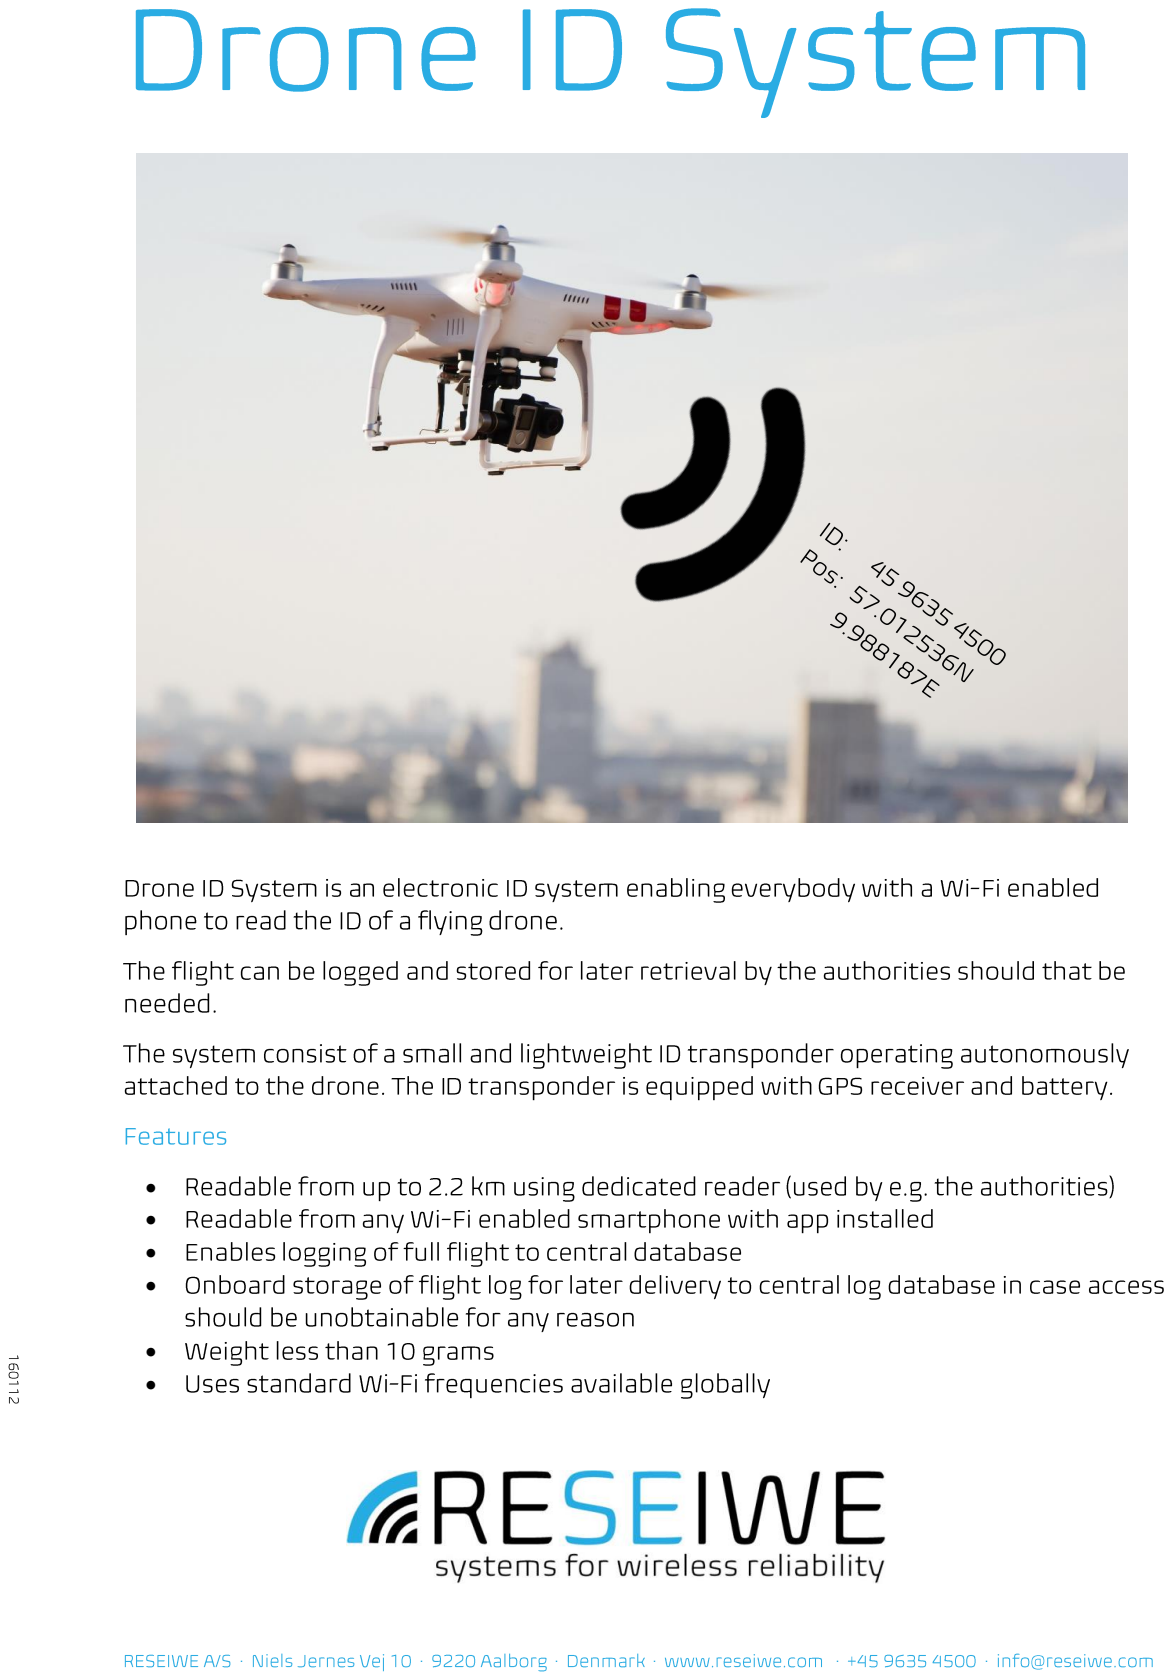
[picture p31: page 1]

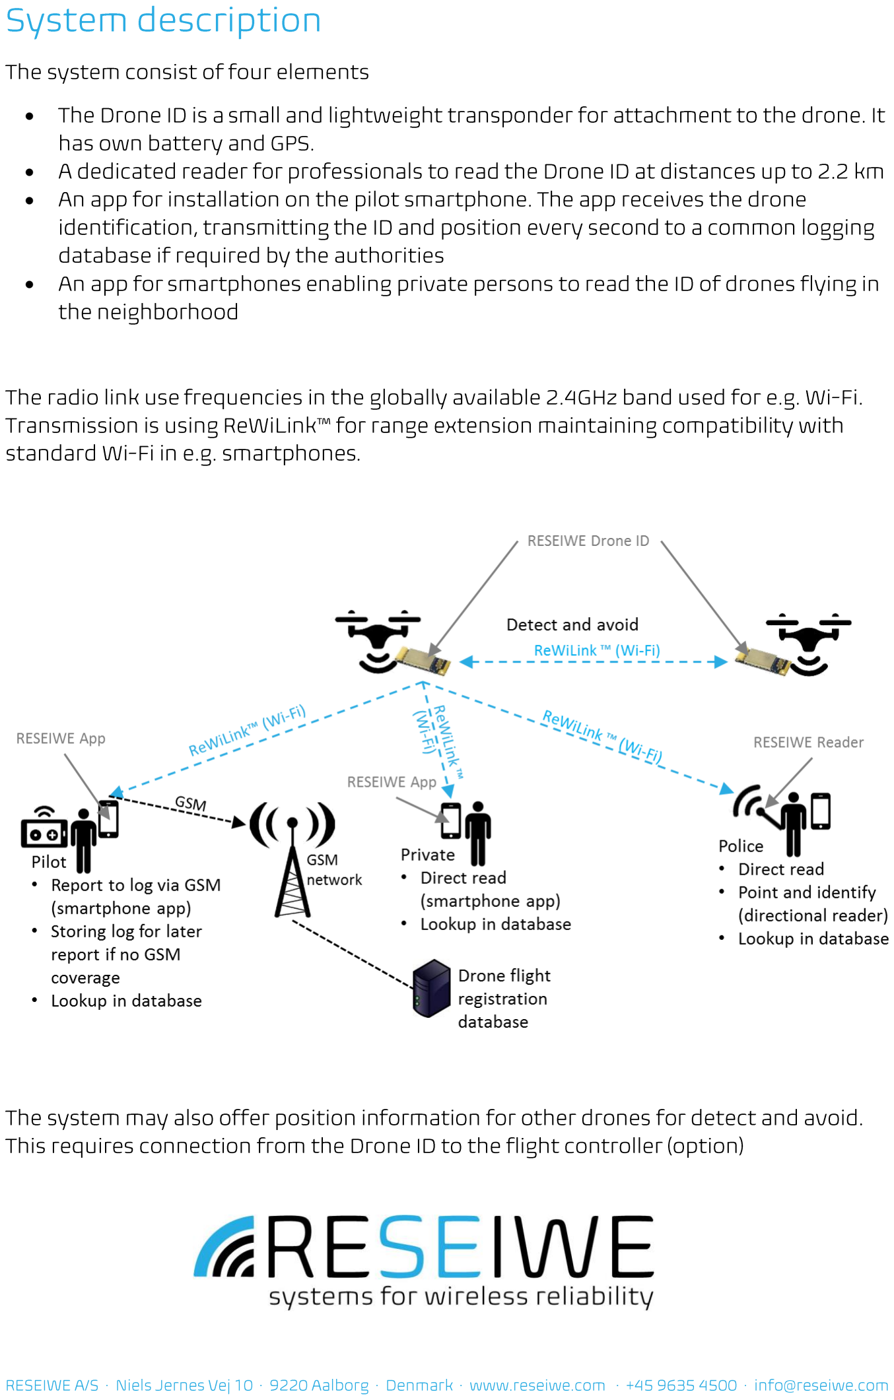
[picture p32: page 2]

••••

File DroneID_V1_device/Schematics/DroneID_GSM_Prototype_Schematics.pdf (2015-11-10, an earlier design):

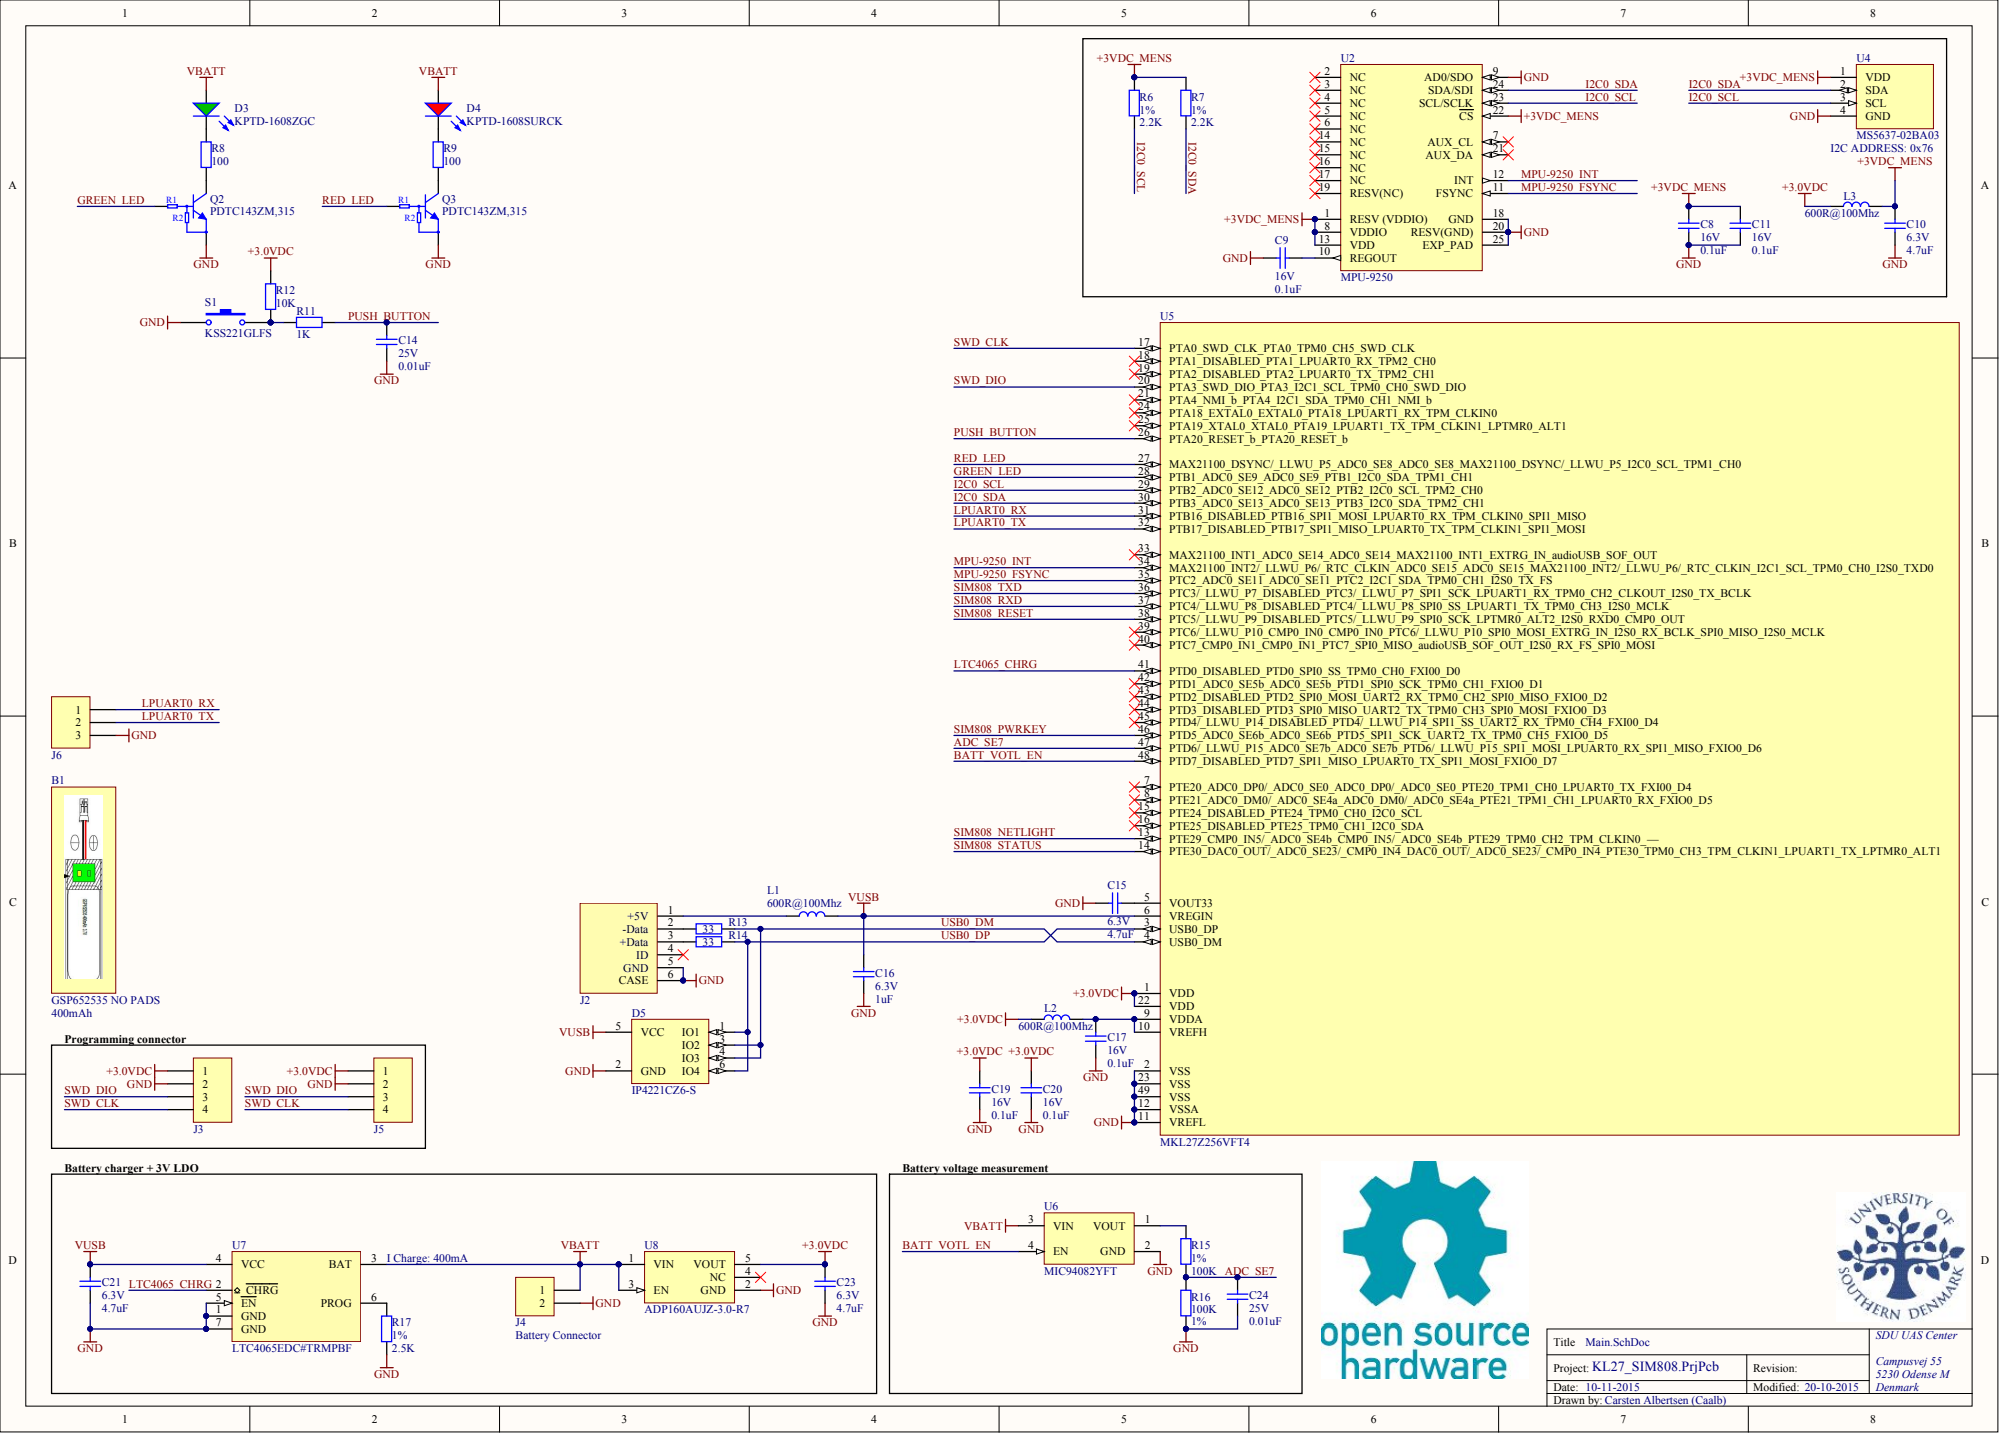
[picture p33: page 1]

4.7uF | GND 1

Title Main.SchDoc | SDU UAS Center Campusvej 55 5230 Odense M Denmark

Project: KL27_SIM808.PrjPcb | Revision:

Date: 10-11-2015 | Modified: 20-10-2015

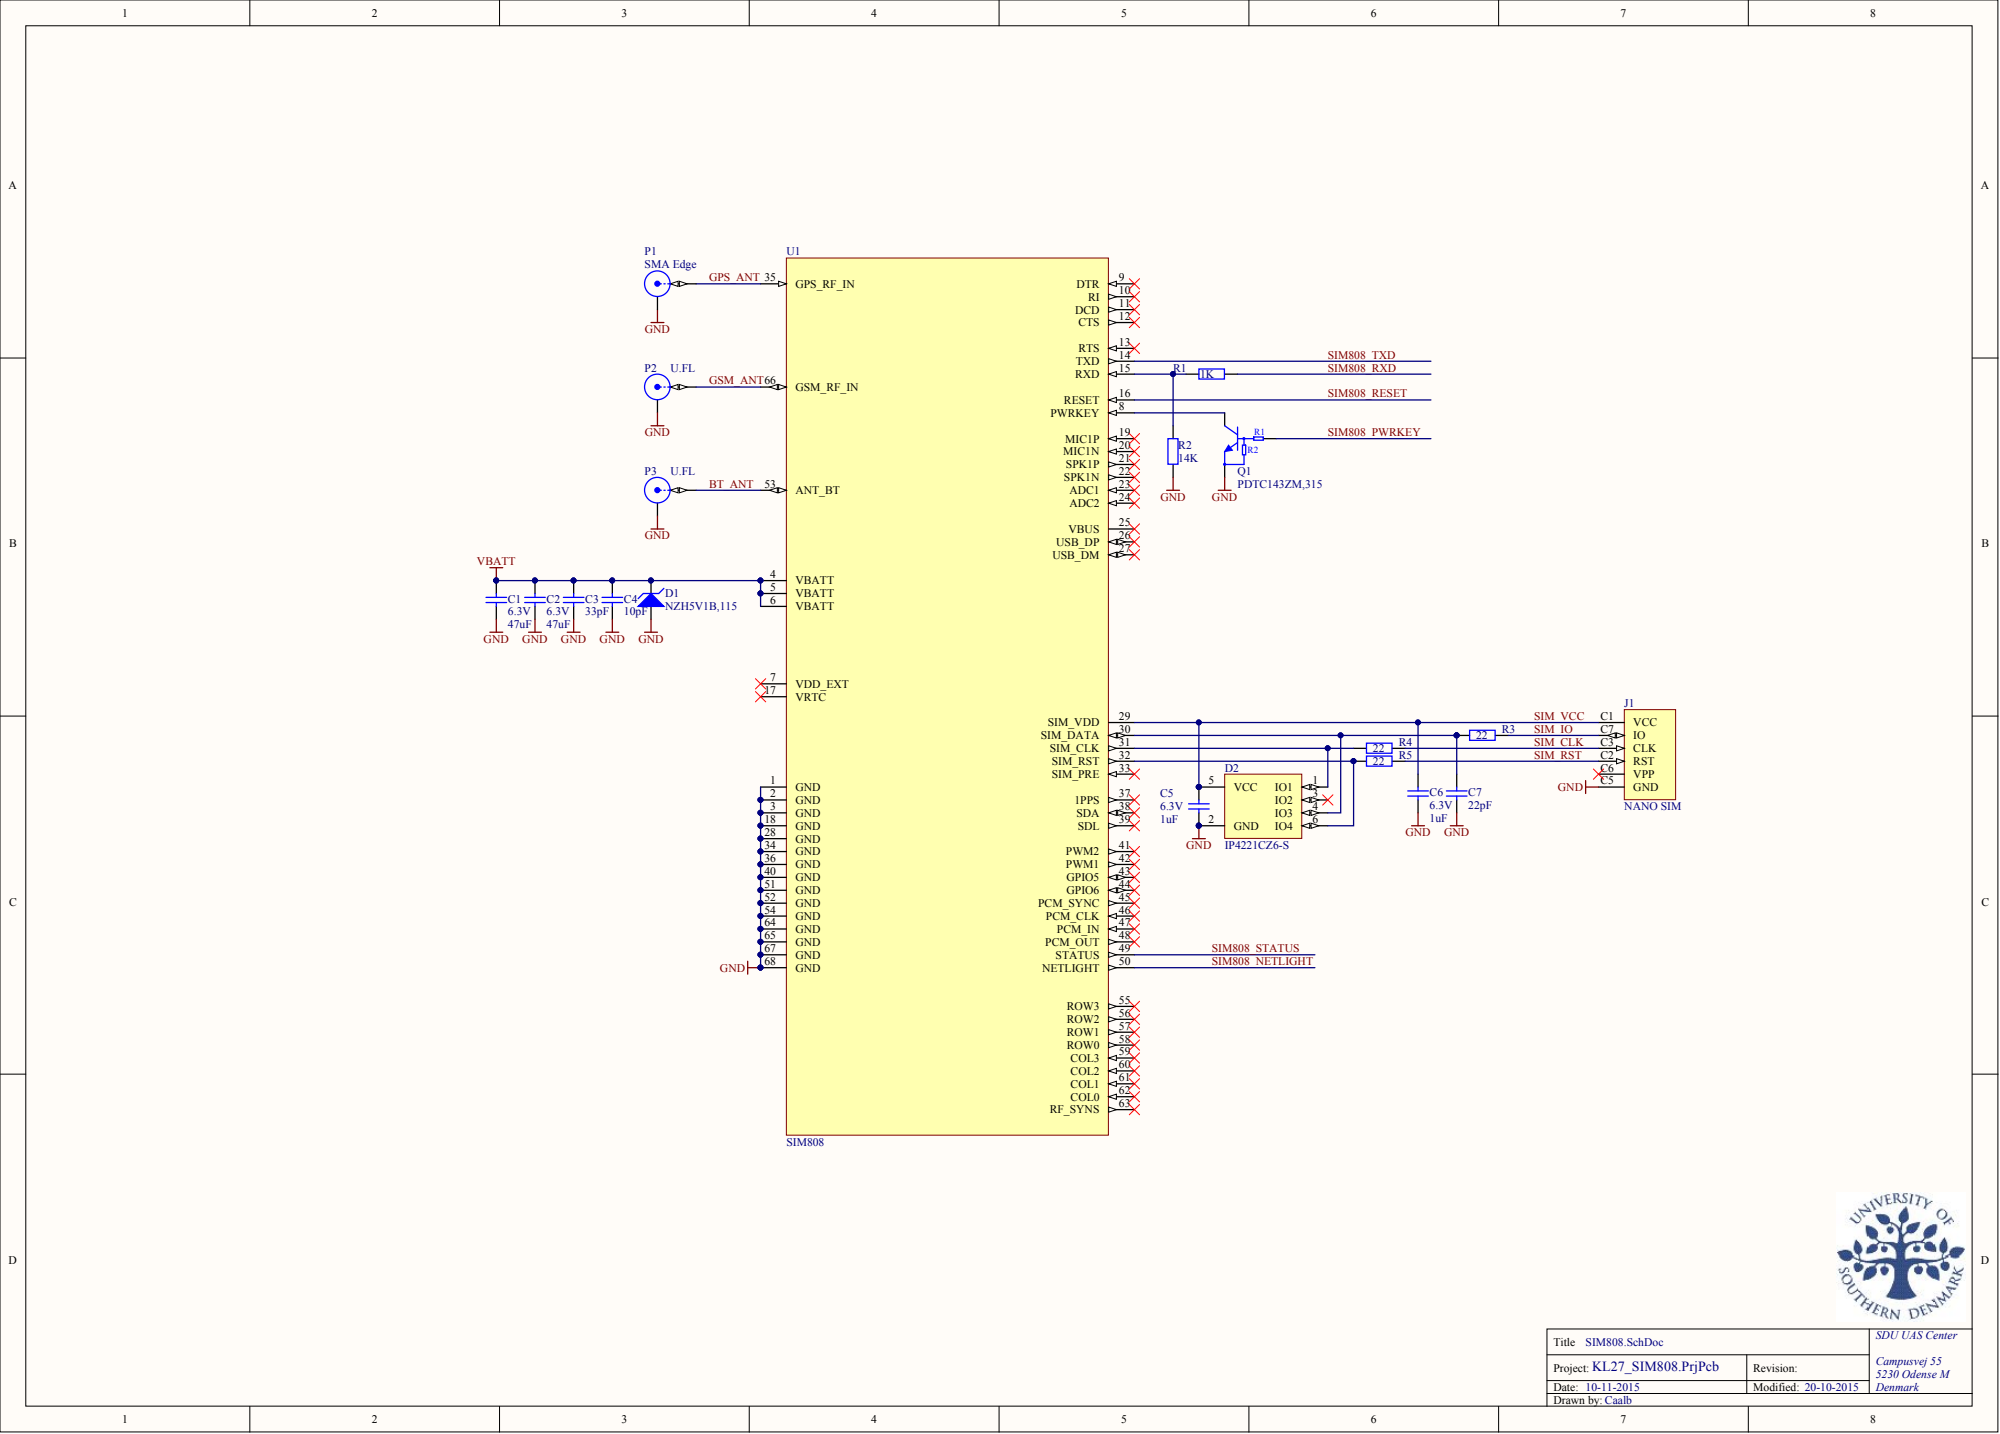
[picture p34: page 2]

SIM_RST

D2 | GND C5 VPP C6

Title SIM808.SchDoc | SDU UAS Center Campusvej 55 5230 Odense M Denmark

Project: KL27_SIM808.PrjPcb | Revision:

Date: 10-11-2015 | Modified: 20-10-2015

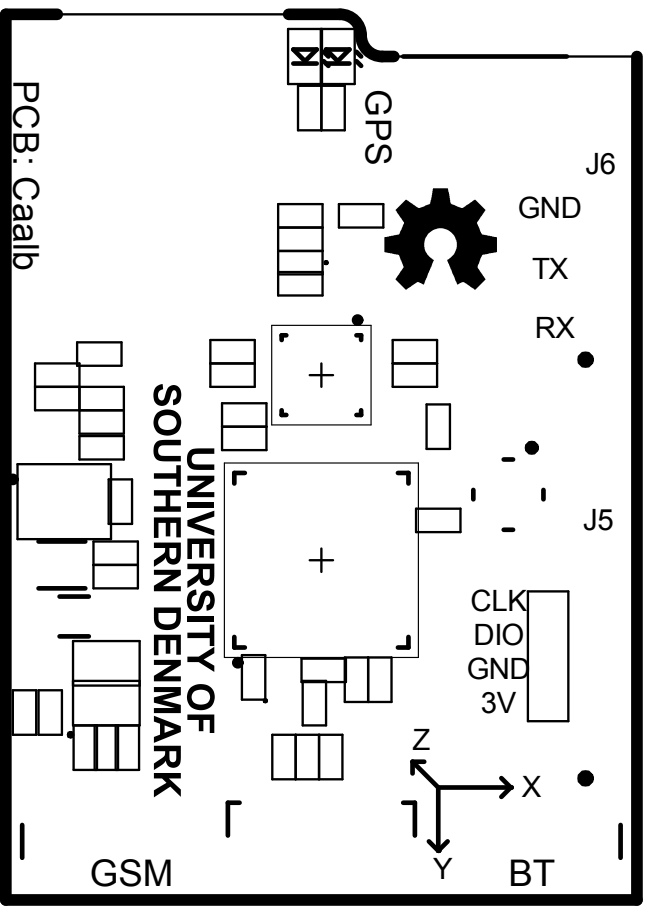
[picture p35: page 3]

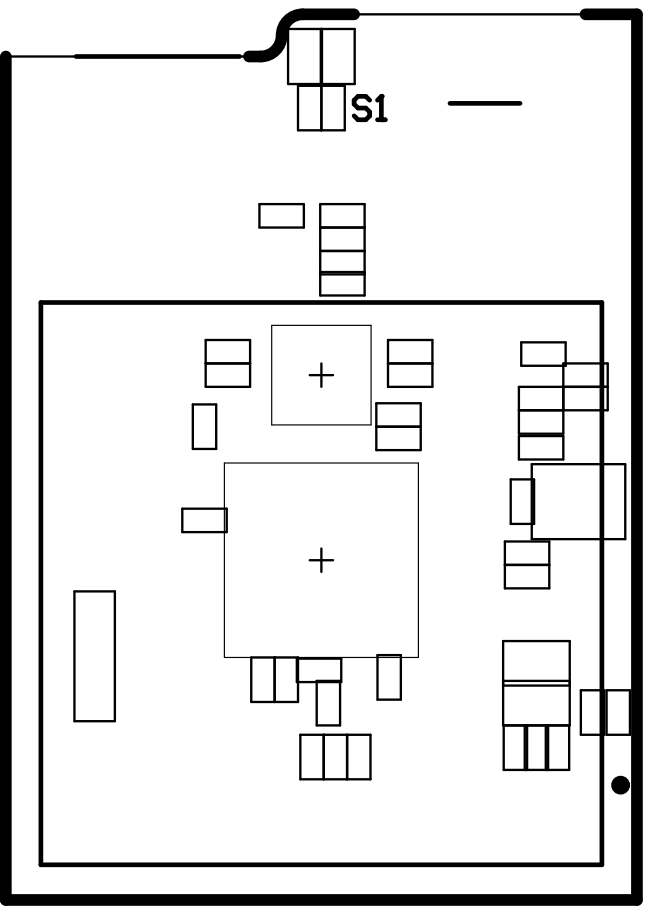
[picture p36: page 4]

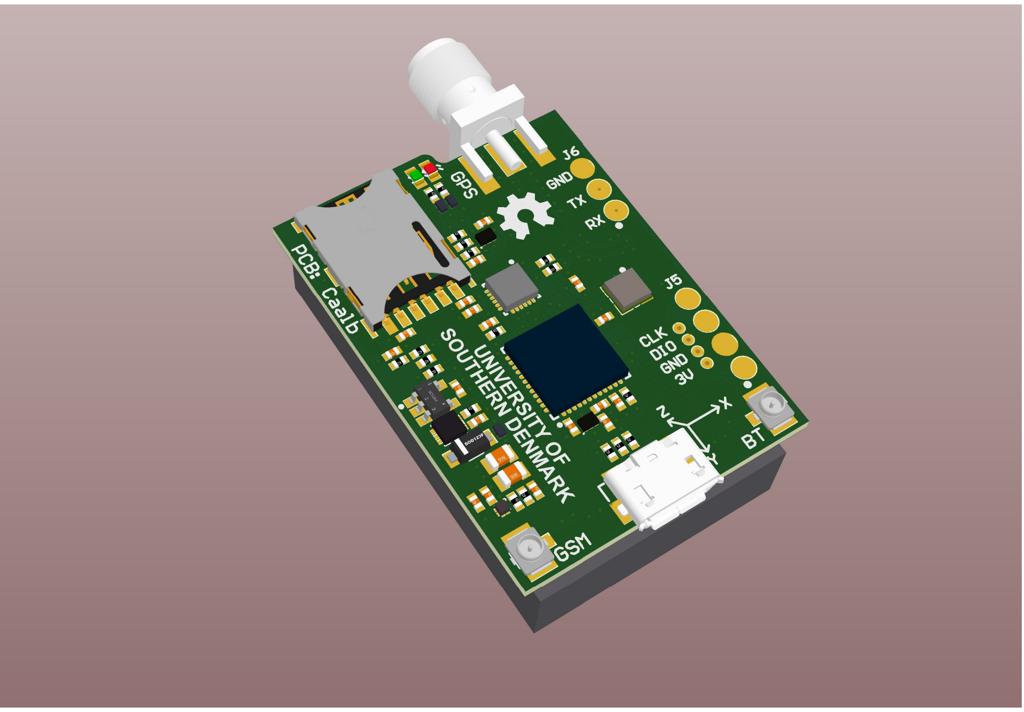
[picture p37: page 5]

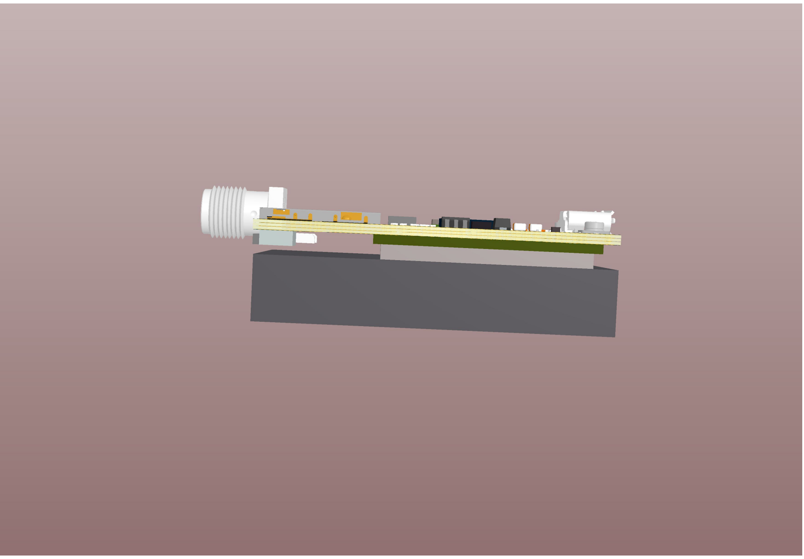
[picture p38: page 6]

Bill of Materials Project: | KL27_SIM808.PrjPcb | Address:
Variant: | None | | Tek Teknologi Ø26-603-1
Creation Date: 10-11-2015 | 14:30:40 | Campusvej 55
Print Date: | 10-11-2015 | 10-11-2015 14:30 | 5230 Odense M
Drawn By: | Carsten Albertsen (Caalb) | Denmark
Value | Comment | Description | Designator | Footprint | Supplier 1 | Supplier Part Number 1 | Supplier 2 | Supplier Part Number 2 | Supplier 3 | Supplier Part Number 3 | Supplier 4 | Supplier Part Number 4 | Quantity
600R@100M hz | BK1005HW601-T | Ferrite bead 300mA, 600mOhm, 600R@100Mhz | L1, L2, L3 | 0402L | RS-Components | | Farnell | 1651725 | Digi-Key | 587-1851-1-ND | Mouser | | 3
100K | 1% | Resistor, SMD, 0402, 0.063W | R15, R16 | 0402R | RS-Components | | Farnell | | Digi-Key | | Mouser | | 2
100 | 1% | Resistor, SMD, 0402, 0.063W | R8, R9 | 0402R | | | | | | | | | 2
47uF | 6.3V | Capacitor, SMD, 0805, X5R | C1, C2 | 0805C | RS-Components | 810-C2012X5R0J476M | Farnell | | Digi-Key | 445-5987-1-ND | Mouser | 810-C2012X5R0J476M | 2
33pF | XXV | Capacitor, SMD, 0402 | C3 | 0402C | RS-Components | | Farnell | | Digi-Key | | Mouser | | 1
33 | 1% | Resistor, SMD, 0402, 0.063W | R13, R14 | 0402R | RS-Components | | Farnell | | Digi-Key | | Mouser | | 2
22pF | XXV | Capacitor, SMD, 0402 | C7 | 0402C | RS-Components | | Farnell | | Digi-Key | | Mouser | | 1
22 | 1% | Resistor, SMD, 0402, 0.063W | R3, R4, R5 | 0402R | RS-Components | | Farnell | | Digi-Key | | Mouser | | 3
14K | 1% | Resistor, SMD, 0402, 0.063W | R2 | 0402R | RS-Components | | Farnell | | Digi-Key | | Mouser | | 1
10pF | XXV | Capacitor, SMD, 0402 | C4 | 0402C | RS-Components | | Farnell | | Digi-Key | | Mouser | | 1
10K | 1% | Resistor, SMD, 0402, 0.063W | R12 | 0402R | RS-Components | | Farnell | | Digi-Key | | Mouser | | 1
4.7uF | 6.3V | Capacitor, SMD, 0402, X5R | C10, C15, C21, C23 | 0402C | RS-Components | 758-2764 | Farnell | | Digi-Key | 1276-1056-1-ND | Mouser | | 4
2.5K | 1% | Resistor, SMD, 0402, 0.063W | R17 | 0402R | RS-Components | | Farnell | | Digi-Key | | Mouser | | 1
2.2K | 1% | Resistor, SMD, 0402, 0.063W | R6, R7 | 0402R | RS-Components | | Farnell | | Digi-Key | | Mouser | | 2
1uF | 6.3V | Capacitor, SMD, 0402, X5R | C5, C6, C16 | 0402C | RS-Components | | Farnell | | Digi-Key | | Mouser | | 3
1K | 1% | Resistor, SMD, 0402, 0.063W | R1, R11 | 0402R | RS-Components | | Farnell | | Digi-Key | | Mouser | | 2
0.1uF | 16V | Capacitor, SMD, 0402, X7R | C8, C9, C11, C17, C19, C20 | 0402C | RS-Components | | Farnell | | Digi-Key | | Mouser | | 6
0.01uF | 25V | Capacitor, SMD, 0402, X7R | C14, C24 | 0402C | RS-Components | | Farnell | 2070373 | Digi-Key | | Mouser | | 2
| 1x2 Header | Header Male 1x2 | J4 | 2x1 Pads 2x2mm SMD | RS-Components | | Farnell | | Digi-Key | | Mouser | | 1
| 1x3 Header | Header Male 1x3 | J6 | 3 x 2.54 Pads TOP | RS-Components | | Farnell | | Digi-Key | | Mouser | | 1
| 1x4 Header | Header Male 1x4 | J3, J5 | 4_Progo_Pin_1 .27, 4 x 2.54 Pads TOP | RS-Components | | Farnell | | Digi-Key | | Mouser | | 2
| ADP160AUJZ-3.0-R7 | Ultralow Quiescent Current, 150 mA, CMOS Linear Regulators | U8 | SOT23-5 | RS-Components | | Farnell | | Digi-Key | ADP160AUJZ-3.0-R7CT-ND | Mouser | | 1
| GSP652535 NO PADS | GSP652535 NO PADS | B1 | GSP652535 NO PADS 2.6mm up | RS-Components | | Farnell | | Digi-Key | | Mouser | | 1
| IP4221CZ6-S | ESD protection for high-speed interfaces | D2, D5 | SOT886 | RS-Components | 725-8789 | Farnell | 1829274 | Digi-Key | 568-6340-6-ND | Mouser | | 2
| KPTD-1608SURCK | LED,SMD,Hyper Red, 800mcd@20mA | D4 | LED0603R | | | | | | | | | 1
| KPTD-1608ZGC | LED,SMD,True-Green, 1000mcd@20mA | D3 | LED0603G | | | | | | | | | 1
| KSS221GLFS | SWITCH TACT SILVR 200GF GULLWING | S1 | KSS221G LFS | | | | | | | | | 1
| LTC4065EDC#T RMPBF | Standalone 750mA Li-Ion Battery Charger in 2 × 2 DFN | U7 | DFN 6 2X2 | RS-Components | 822-5935 | Farnell | 1663910 | Digi-Key | LTC4065EDC#TRMPBFCT-ND | Mouser | | 1
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

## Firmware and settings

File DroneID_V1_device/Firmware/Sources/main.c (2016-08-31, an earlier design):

/****************************************************************************
* Main file for DroneID
* Copyright (c) 2015, Martin Skriver <MaSkr@mmmi.sdu.dk> & <MaSkr09@gmail.com>
* All rights reserved.
*
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
* THIS SOFTWARE IS PROVIDED BY THE COPYRIGHT HOLDERS AND CONTRIBUTORS "AS IS" AND
* ANY EXPRESS OR IMPLIED WARRANTIES, INCLUDING, BUT NOT LIMITED TO, THE IMPLIED
* WARRANTIES OF MERCHANTABILITY AND FITNESS FOR A PARTICULAR PURPOSE ARE
* DISCLAIMED. IN NO EVENT SHALL <COPYRIGHT HOLDER> BE LIABLE FOR ANY
* DIRECT, INDIRECT, INCIDENTAL, SPECIAL, EXEMPLARY, OR CONSEQUENTIAL DAMAGES
* (INCLUDING, BUT NOT LIMITED TO, PROCUREMENT OF SUBSTITUTE GOODS OR SERVICES;
* LOSS OF USE, DATA, OR PROFITS; OR BUSINESS INTERRUPTION) HOWEVER CAUSED AND
* ON ANY THEORY OF LIABILITY, WHETHER IN CONTRACT, STRICT LIABILITY, OR TORT
* (INCLUDING NEGLIGENCE OR OTHERWISE) ARISING IN ANY WAY OUT OF THE USE OF THIS
* SOFTWARE, EVEN IF ADVISED OF THE POSSIBILITY OF SUCH DAMAGE.
*****************************************************************************
* File: main.c
* Purpose: Init hardware, OS and task create
* Project: DroneID
* Author: Martin Skriver <MaSkr@mmmi.sdu.dk> & <MaSkr09@gmail.com>
* ****************************************************************************
* Log:
* Created:  2015-09-16 Martin Skriver, 	Source written
****************************************************************************/

/***************************************************************************/
/* application includes */
/* Including needed modules to compile this module/procedure */
#include "Cpu.h"
#include "Events.h"
#include "clockMan1.h"
#include "pin_mux.h"
#include "osa1.h"
#include "free_rtos.h"
#include "DbgCs1.h"
#include "gpio1.h"
#include "tpmTmr1.h"
#include "pwrMan1.h"
#include "lpuartCom1.h"
#include "adConv1.h"
#include "i2cCom1.h"
#include "Init_Config.h"
/* User includes (#include below this line is not maintained by Processor Expert) */
#include "Tasks/drone_id_task/drone_id_task.h"
#include "Tasks/Virtual_Com/virtual_com.h"
#include "Tasks/GPS_task/gps.h"
#include "Tasks/GSM_uart_task/gsm_uart_send.h"
#include "Tasks/GSM_uart_task/gsm_uart_receive.h"
#include "Tasks/user_input_task/user_input_task.h"
#include "Tasks/LED_task/led_task.h"
#include "Tasks/button_task/button_task.h"
#include "Tasks/ADC_task/adc_task.h"
#include "Tasks/IMU_task/imu_task.h"
#include "Tasks/tracking_timer_task/tracking_timer_task.h"

/***************************************************************************/
/* Main function */
/*lint -save  -e970 Disable MISRA rule (6.3) checking. */
int main(void)
/*lint -restore Enable MISRA rule (6.3) checking. */
{
  /* Write your local variable definition here */

  /*** Processor Expert internal initialization. DON'T REMOVE THIS CODE!!! ***/
  PE_low_level_init();
  /*** End of Processor Expert internal initialization.                    ***/

  /* Write your code here */
	xTaskCreate(
		gps_task,  /* task function */
		"GPS_TASK", /* task name for kernel awareness */
		configMINIMAL_STACK_SIZE, /* task stack size */
		(void*)NULL, /* optional task startup argument */
		tskIDLE_PRIORITY+10,  /* initial priority */
		&GPS_task_handle); /* task handle */
	configASSERT( GPS_task_handle );

	xTaskCreate(
		drone_id_main_task,  /* task function */
		"DRONE_ID_TASK", /* task name for kernel awareness */
		configMINIMAL_STACK_SIZE, /* task stack size */
		(void*)NULL, /* optional task startup argument */
		tskIDLE_PRIORITY+10,  /* initial priority */
		&drone_id_task_handle); /* task handle */
	configASSERT( drone_id_task_handle );

	xTaskCreate(
		user_input_main_task,  /* task function */
		"USER_INPUT_TASK", /* task name for kernel awareness */
		configMINIMAL_STACK_SIZE, /* task stack size */
		(void*)NULL, /* optional task startup argument */
		tskIDLE_PRIORITY+10,  /* initial priority */
		NULL); /* task handle */

	xTaskCreate(
		vc_task,  /* task function */
		"VC_TASK", /* task name for kernel awareness */
		configMINIMAL_STACK_SIZE, /* task stack size */
		(void*)NULL, /* optional task startup argument */
		tskIDLE_PRIORITY+10,  /* initial priority */
		&vc_task_handle); /* task handle */
	configASSERT( vc_task_handle );

	xTaskCreate(
		gsm_uart_send_task,  /* task function */
		"GSM_UART_SEND", /* task name for kernel awareness */
		configMINIMAL_STACK_SIZE, /* task stack size */
		(void*)NULL, /* optional task startup argument */
		tskIDLE_PRIORITY+10,  /* initial priority */
		&gsm_uart_send_task_handle); /* task handle */
	configASSERT( gsm_uart_send_task_handle );

	xTaskCreate(
		gsm_uart_receive_task,  /* task function */
		"GSM_UART_RECEIVE", /* task name for kernel awareness */
		configMINIMAL_STACK_SIZE, /* task stack size */
		(void*)NULL, /* optional task startup argument */
		tskIDLE_PRIORITY+10,  /* initial priority */
		&gsm_uart_receive_task_handle); /* task handle */
	configASSERT( gsm_uart_receive_task_handle );

	xTaskCreate(
		led_main_task, /* task function */
		"LED_TASK", /* task name for kernel awareness */
		configMINIMAL_STACK_SIZE, /* task stack size */
		(void*)NULL, /* optional task startup argument */
		tskIDLE_PRIORITY+10,  /* initial priority */
		NULL); /* task handle */

	xTaskCreate(
		button_main_task,  /* task function */
		"BUTTON_TASK", /* task name for kernel awareness */
		configMINIMAL_STACK_SIZE, /* task stack size */
		(void*)NULL, /* optional task startup argument */
		tskIDLE_PRIORITY+10,  /* initial priority */
		&button_main_task_handle); /* task handle */
	configASSERT( button_main_task_handle );

	xTaskCreate(
		adc_main_task,  /* task function */
		"ADC_TASK", /* task name for kernel awareness */
		configMINIMAL_STACK_SIZE, /* task stack size */
		(void*)NULL, /* optional task startup argument */
		configMAX_PRIORITIES - 10, //tskIDLE_PRIORITY,  /* initial priority */
		&adc_main_task_handle); /* task handle */
	configASSERT( adc_main_task_handle );

	xTaskCreate(
		tracking_timer_task,  /* task function */
		"TRACKING_TIMER", /* task name for kernel awareness */
		configMINIMAL_STACK_SIZE, /* task stack size */
		(void*)NULL, /* optional task startup argument */
		tskIDLE_PRIORITY+10,  /* initial priority */
		&tracking_timer_handle); /* task handle */
	configASSERT( tracking_timer_handle );

	xTaskCreate(
		imu_main_task,  /* task function */
		"IMU_TASK", /* task name for kernel awareness */
		configMINIMAL_STACK_SIZE, /* task stack size */
		(void*)NULL, /* optional task startup argument */
		tskIDLE_PRIORITY+10,  /* initial priority */
		&imu_main_task_handle); /* task handle */
	configASSERT( imu_main_task_handle );


  /*** Don't write any code pass this line, or it will be deleted during code generation. ***/
  /*** RTOS startup code. Macro PEX_RTOS_START is defined by the RTOS component. DON'T MODIFY THIS CODE!!! ***/
  #ifdef PEX_RTOS_START
    PEX_RTOS_START();                  /* Startup of the selected RTOS. Macro is defined by the RTOS component. */
  #endif
  /*** End of RTOS startup code.  ***/
  /*** Processor Expert end of main routine. DON'T MODIFY THIS CODE!!! ***/
  for(;;){}
  /*** Processor Expert end of main routine. DON'T WRITE CODE BELOW!!! ***/
} /*** End of main routine. DO NOT MODIFY THIS TEXT!!! ***/
/* END main */
/*!
** @}
*/
/*
** ###################################################################
**
**     This file was created by Processor Expert 10.5 [05.21]
**     for the Freescale Kinetis series of microcontrollers.
**
** ###################################################################
*/

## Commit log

2015-11-10 Updated readme and added current version of the schematics for the DroneID GSM prototype.
2015-12-02 Added cabinet 3D print stl files.
    [00-00-001.stl, 00-00-002.stl]
2015-12-02 Moved schematics one level down.
2016-05-30 Renamed the DroneID_GSM_Prototype_2015 directory.
    [00-00-001.stl, 00-00-002.stl]
2016-10-26 Renamed DroneID V1 directory.
    [00-00-001.stl, 00-00-002.stl]
2016-10-26 Prepared directory for DroneID V2 device.
